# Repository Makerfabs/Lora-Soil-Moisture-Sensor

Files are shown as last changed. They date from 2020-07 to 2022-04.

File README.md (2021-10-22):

# Lora Soil Moisture Sensor

[toc]

# Makerfabs

[Makerfabs home page](https://www.makerfabs.com/)

[Makerfabs Wiki](https://makerfabs.com/wiki/index.php?title=Main_Page)

# Lora Soil Moisture Sensor

## Introduce

Product Link: [Lora_Soil_Moisture_Sensor](https://www.makerfabs.com/lora-soil-moisture-sensor.html)

Wiki Link:  [Lora_Soil_Moisture_Sensor_V3](https://www.makerfabs.com/wiki/index.php?title=Lora_Soil_Moisture_Sensor_V3)

The Lora soil moisture sensor is based on Atmel's Atmega328P, it collects local air temperature/ humidity with sensor AHT10, and detect the soil humidity with capacitor-humility measurement solution with MCU clock, and transmit the local environment data to the gateway, with Lora communication, suit for applications for smart-farm, irrigation, agriculture, etc. 

In applications, always you do not need to check the air/soil state continuously, have a test of them for few seconds after then minutes/hours sleeping is normally Ok for most projects. To save power, there the Air/ Soil measuring functional could be shut down in the working, so they can be only powered ON a short time and then a long time power off. With MCU in sleeping mode and low power consumption Lora module, this module works ok with 2 AAA battery more than one year. Besides, this sensor is coated with waterproof paint, which makes it longer working time in damp soil. 

## Feature

- Classic ATMEL AVR 8-bit Atmega328P, with Arduino Pro Mini(3.3V/8M bootloader pre-loaded) .
- Capacitor-humility measurement.
- AHT10 temperature and humidity sensor.
- Working with 2 AAA more than one years.
- 3D printed case.
- Waterproof coating.
- Unique ID, can be used directly without secondary programming.

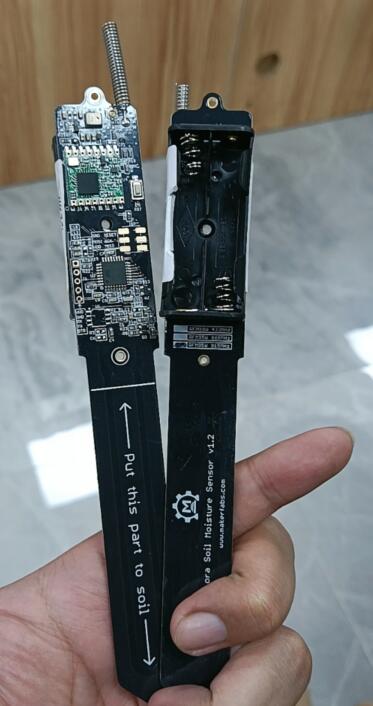
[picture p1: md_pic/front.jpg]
front


# Version
## V3 
In the latest version, the 555 chip has been removed so that the sleep current can be as low as 7.1uA. And added UID, can be used directly.

**More details, see readme. md in the [V3](https://github.com/Makerfabs/Lora-Soil-Moisture-Sensor/tree/master/V3) folder.**

## V2
Old version, containing 555 chip. A number of items are provided as references.

**More details, see readme. md in the [V2](https://github.com/Makerfabs/Lora-Soil-Moisture-Sensor/tree/master/V2) folder.**

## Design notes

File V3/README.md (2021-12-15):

# Lora Soil Moisture Sensor V3

```c++
/*
Version:		V5.0
Author:			UNKOWN
Create Date:	UNKOWN
Note:
	2021/12/15	V5.2: Fix RadioHead demo can't setModemConfig. 
	2021/11/17  V5.1: Fix code bug,example "ESP32 Receiver" pin define wrong.
	2021/10/22	V5.0: Modify the document structure. 
	2021/9/26	V4.0: The new hardware removed the 555 chip, updated the BOM, and significantly improved battery life.
	2021/8/24	V3.1: Now can read ADC value without 555.
	2021/7/22	V3.0: Now support Lorawan to TTN.
	2020/10/26	v2.2: Add a power-save verson.Using watch dog and sleep mode.
	2020/8/24	v2.1: Add pcb file.
    2020/7/24	v2.0: Rebuid readme,add pic. By Vincent
*/
```

[toc]

# Makerfabs

[Makerfabs home page](https://www.makerfabs.com/)

[Makerfabs Wiki](https://makerfabs.com/wiki/index.php?title=Main_Page)

# Lora Soil Moisture Sensor V3

## Introduce

Product Link: [Lora_Soil_Moisture_Sensor](https://www.makerfabs.com/lora-soil-moisture-sensor.html)

Wiki Link:  [Lora_Soil_Moisture_Sensor_V3](https://www.makerfabs.com/wiki/index.php?title=Lora_Soil_Moisture_Sensor_V3)

The Lora soil moisture sensor is based on Atmel's Atmega328P, it collects local air temperature/ humidity with sensor AHT10, and detect the soil humidity with capacitor-humility measurement solution with MCU clock, and transmit the local environment data to the gateway, with Lora communication, suit for applications for smart-farm, irrigation, agriculture, etc. 

In applications, always you do not need to check the air/soil state continuously, have a test of them for few seconds after then minutes/hours sleeping is normally Ok for most projects. To save power, there the Air/ Soil measuring functional could be shut down in the working, so they can be only powered ON a short time and then a long time power off. With MCU in sleeping mode and low power consumption Lora module, this module works ok with 2 AAA battery more than one year. Besides, this sensor is coated with waterproof paint, which makes it longer working time in damp soil. 

## Feature

- Classic ATMEL AVR 8-bit Atmega328P, with Arduino Pro Mini(3.3V/8M bootloader pre-loaded) .
- Capacitor-humility measurement.
- AHT10 temperature and humidity sensor.
- Working with 2 AAA more than one years.
- 3D printed case.
- Waterproof coating.
- Unique ID, can be used directly without secondary programming.

front

## Hardware Update

We removed the 555 chip and made a lot of changes to the code. The current soil moisture test uses MCU clock pulses instead of those generated by the 555 chip. Sleep mode has also been optimized more.

Detailed power consumption data is being edited....

## Firmware

### Moisture_LowPower_RadioLib_v2.1.ino

The latest firmware is in:

V3\firmware\Moisture_LowPower_RadioLib_v2.1

### How to use
- The code contains a unique ID and sends Lora messages every 75 minutes in the following format:

```c++
String message = 
    "INEDX:" + (String)packetnum + " H:" + (String)humidity + 
    " T:" + (String)temperature + " ADC:" + (String)sensorValue + 
    " BAT:" + (String)batValue;

String back_str = node_id + " REPLY : SOIL " + message;

//Full message example:
//ID010123 REPLY : SOIL INEDX:0 H:48.85 T:30.50 ADC:896 BAT:1016
```

- If you want to change the time, you can change it:

```c++
//Set sleep time, when value is 1 almost sleep 20s,when value is 450, almost 1 hour.
//Each sleep cycle almost 8s.
#define SLEEP_CYCLE 1

```

- The degree of soil ADC is about 900 in air (completely dry) and 600 in water (completely wet).

## Usage

### Receiver

A simple receiver demo is provided. You can use another Lora Moisture or Maduino Lora Radio as the receiver.

Receive data through serial port display.

The receiver code is in: V3\example\Lora_Receiver_v1.0

### ESP32 Receiver

A simple receiver demo is provided. You can use a MakePython Lora as the receiver.

Receive data and display on SSD1306.

### RadioHead Demo

The default parameters of RadioLib can reach about 800m communication distance, of course can be further, but we do not have time to debug Lora parameters.

We provide an example that can reach 1.7km communication distance, which was debugged by a former colleague. It used to depend on some AVR libraries This made ESP32 unable to complier ReadHead library at the time, so we switched to RadioLib instead. But the latest version, ReadHead is available under ESP32.

Please download the latest [RadioHead](http://www.airspayce.com/mikem/arduino/RadioHead/)

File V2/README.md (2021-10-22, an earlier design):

# Lora-Soil-Moisture-Sensor V2

```c++
/*
Version:		V4.0
Author:			UNKOWN
Create Date:	UNKOWN
Note:
	2021/9/26	V4.0: The new hardware removed the 555 chip, updated the BOM, and significantly improved battery life.
	2021/8/24	V3.1: Now can read ADC value without 555.
	2021/7/22	V3.0: Now support Lorawan to TTN.
	2020/10/26	v2.2: Add a power-save verson.Using watch dog and sleep mode.
	2020/8/24	v2.1: Add pcb file.
    2020/7/24	v2.0: Rebuid readme,add pic. By Vincent
*/
```

[toc]

# *Only available before October 2021, including the 555 chip version.*

# Introduce

The Lora soil moisture sensor is based on Atmel's Atmega328P, it collect local air temperature/ humidity with sensor AHT10, and detect the soil humidity with capacitor-humility measurement solution with 555, and transmit the local environment data to the gateway, with Lora communication, suit for applications for smart-farm, irrigation, agriculture, etc.

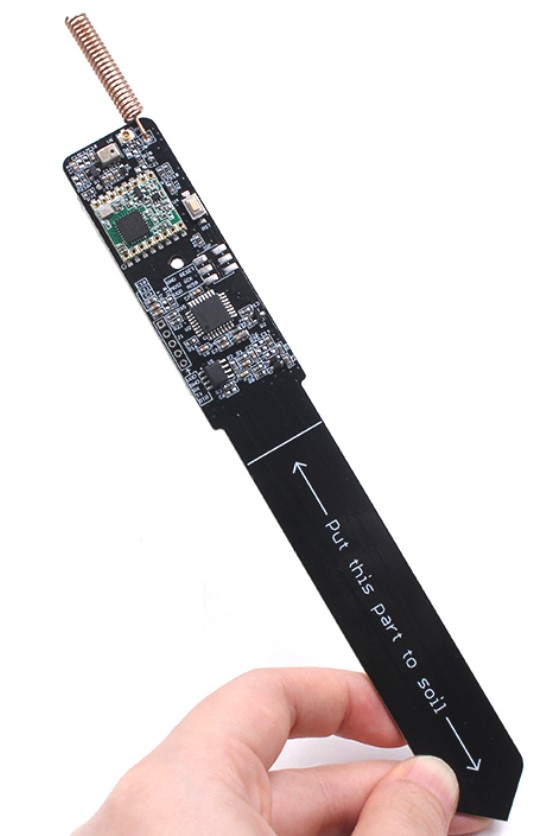
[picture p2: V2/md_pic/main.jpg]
relay


- You can get one from: [Lora_Soil_Moisture_Sensor](https://www.makerfabs.com/lora-soil-moisture-sensor.html)

- Hardware and detailed instructions please visit Wiki page:  [Lora_Soil_Moisture_Sensor Wiki](https://www.makerfabs.com/wiki/index.php?title=Lora_Soil_Moisture_Sensor)

# Related Projects

## [Project_Soil-Moisture-Sensor-Wifi](https://github.com/Makerfabs/Project_Soil-Moisture-Sensor-Wifi)

- Control relay through wifi.

- [youtube:Lora soil moisture wifi](https://youtu.be/1wYAwtzNxJU)

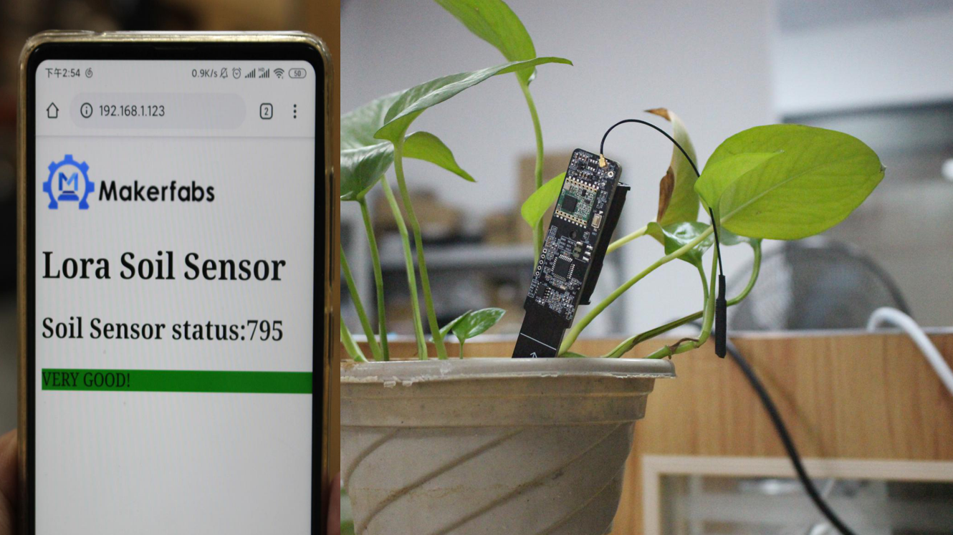
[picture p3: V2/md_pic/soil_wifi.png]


## [Lora IoT Irrigation System](https://github.com/Makerfabs/Project_IoT-Irrigation-System)

- IoT agricultural irrigation experiment based on Lora communication.
- [YOUTUBE:Lora IoT Irrigation System - Outdoor Simulation Test](https://youtu.be/0mY6Ox0YvRk)

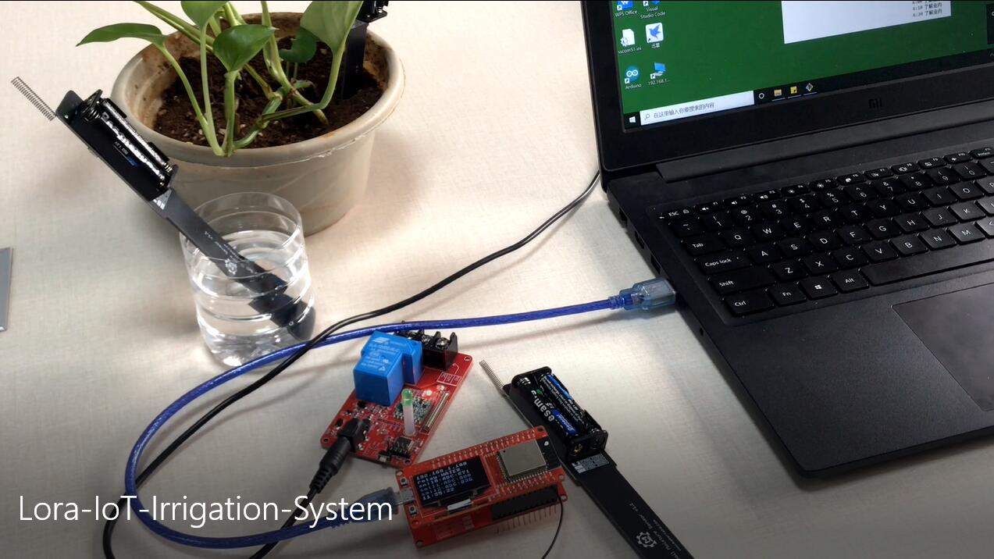
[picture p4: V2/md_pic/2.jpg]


# Example List

## LoraTransmitterADCAHT10

Default factory firmware, can measure air temperature and humidity and soil moisture, and send through Lora.

## PowerSaveMode_SoilSensor

By putting the 328p and SX1278 to sleep, you can reduce power consumption by waking them up regularly.

## lora_soil_no555

Instead of the 555 chip, we can divide the clock source by 328P.

Need to remove the R3 resistor from the PCB. And ADC results may be different from previous ones, around 910 in air and 740 in water.

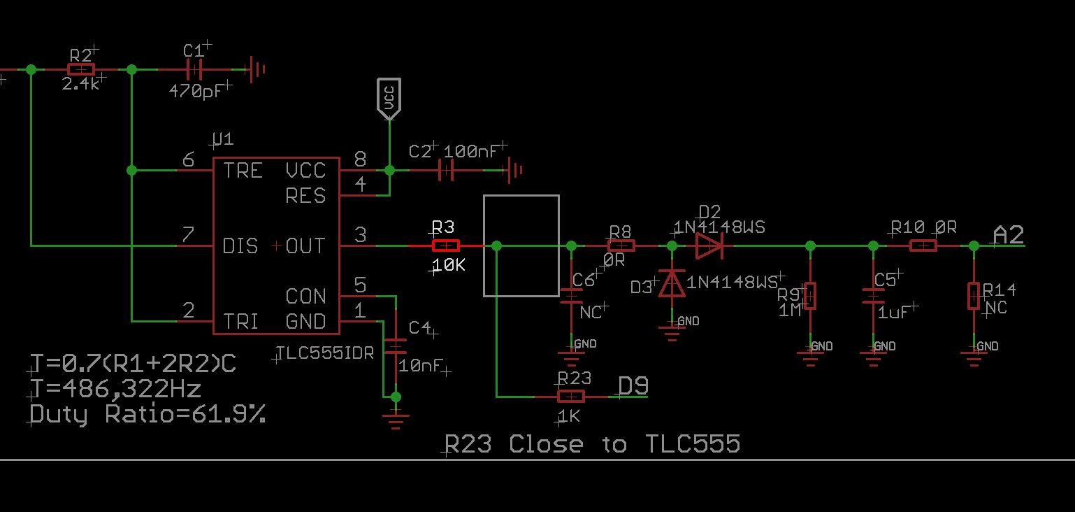
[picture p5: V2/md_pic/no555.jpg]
no555


## About Lorawan

An example of connecting to Lorawan is provided.For details on how to set TTN, see the Wiki：[Maduino_Zero_LoRaWAN_Node](https://www.makerfabs.com/wiki/index.php?title=Maduino_Zero_LoRaWAN_Node)

**Only supporting the EU-868 and US-915**

### Setup Library

Download from ：[arduino-lmic](https://github.com/matthijskooijman/arduino-lmic)

And installer .zip library

### Set EUI

To connect through OTAA, you need to replace the following code with your own DEVEUI, APPEUI, and APPKEY.

Notice that DEVEUI and APPEUI are little-endian, but APPKEY is big endian.

```c++
// This EUI must be in little-endian format, so least-significant-byte
// first. When copying an EUI from ttnctl output, this means to reverse
// the bytes. For TTN issued EUIs the last bytes should be 0xD5, 0xB3,
// 0x70.
//70B3D57ED0041DA0
//static const u1_t PROGMEM APPEUI[8]={ 0x70, 0xB3, 0xD5, 0x7E, 0xD0, 0x04, 0x1D, 0xA0 };
static const u1_t PROGMEM APPEUI[8]={ 0xA0, 0x1D, 0x04, 0xD0, 0x7E, 0xD5, 0xB3, 0x70 };
void os_getArtEui (u1_t* buf) { memcpy_P(buf, APPEUI, 8);}

// This should also be in little endian format, see above.
//D896E0FF00000888
//static const u1_t PROGMEM DEVEUI[8]={ 0xD8, 0x96, 0xE0, 0xFF, 0x00, 0x00, 0x08, 0x88 };
static const u1_t PROGMEM DEVEUI[8]={ 0x88, 0x08, 0x00, 0x00, 0xFF, 0xE0, 0x96, 0xD8 };
void os_getDevEui (u1_t* buf) { memcpy_P(buf, DEVEUI, 8);}

// This key should be in big endian format (or, since it is not really a
// number but a block of memory, endianness does not really apply). In
// practice, a key taken from ttnctl can be copied as-is.
// The key shown here is the semtech default key.
//DBA8 0380 77B1 42A7 3CFA D1EB 2F0C 8FC4
static const u1_t PROGMEM APPKEY[16] = { 0xDB, 0xA8, 0x03, 0x80, 0x77, 0xB1, 0x42, 0xA7, 0x3C, 0xFA, 0xD1, 0xEB, 0x2F, 0x0C, 0x8F, 0xC4 };
//static const u1_t PROGMEM APPKEY[16] = { 0xC4, 0x8F, 0x0C, 0x2F, 0xEB, 0xD1, 0xFA, 0x3C, 0xA7, 0x42, 0xB1, 0x77, 0x80, 0x03, 0xA8, 0xDB };
void os_getDevKey (u1_t* buf) {  memcpy_P(buf, APPKEY, 16);}
```

The code locations are /lorawan/OTAA_328p and /lorawan/OTAA_soil.

It takes a long, patient wait to connect, about 3 to 10 minutes. I don't know why.

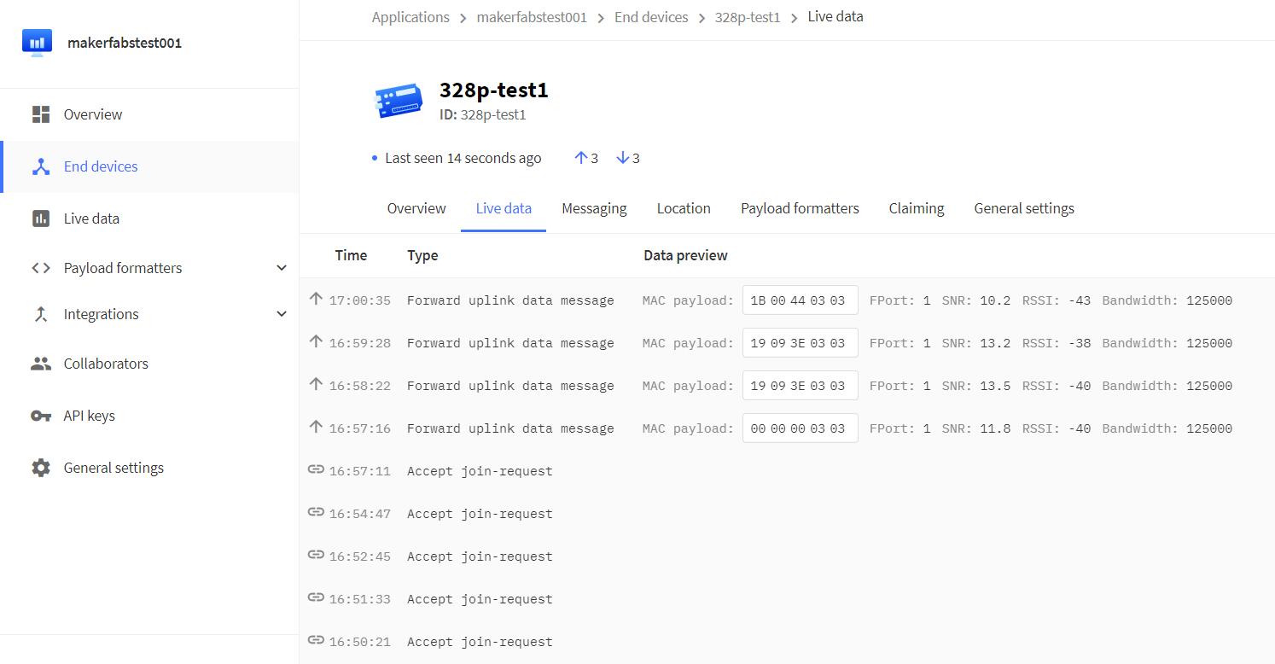
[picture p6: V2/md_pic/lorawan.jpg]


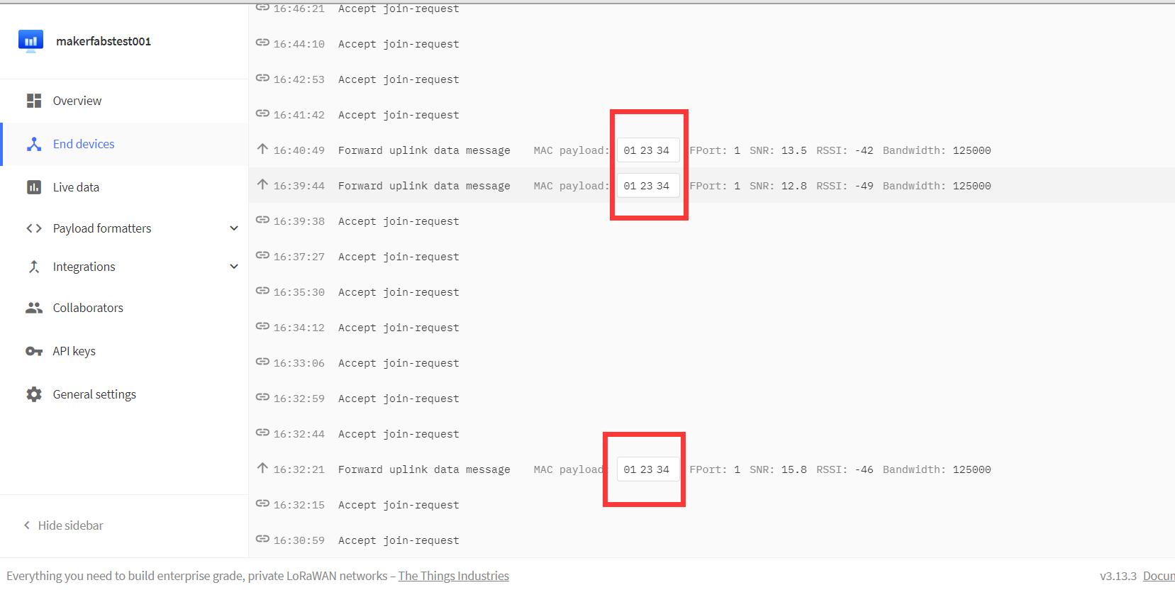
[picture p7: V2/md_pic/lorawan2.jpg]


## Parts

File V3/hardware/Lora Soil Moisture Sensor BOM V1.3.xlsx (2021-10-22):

Lora Capacitive Soil Moisture Sensor v1.3
Part | Value | Device | Package | Description | Qty
双面胶 |  |  |  |  | 1 | 双面胶将电池座黏到PCB上之后焊接
BAT1 | 2节AAA电池座，带针 |  |  |  | 1
ANT | 天线座 | ANTENNA-U-FL | 4P-U-FL |  | 1
C10,C11,C13,C14 | 10uF | C-0603 | 0603 | Ceramic Capacitors | 4
C1 | 470pF,0603 | C-0603 | 0603 |  | 1
C2,C3,C7,C8,C9,C12,C16,C18,C19 | 100nF | C-0603 | 0603 |  | 9
C4 | 10nF | C-0603 | 0603 |  | 1
C5 | 1uF | C-0603 | 0603 |  | 1
D2,D3,D4 | 1N4148WS | SOD-323 | SOD-323 |  | 3
R5,R9,R26 | 1M/1% | R-0603 | R0603 |  | 4
R27 | 470K/1% | R-0603 | R0603 |  | 1
R4,R12,R15,R22, | 10K | R-0603 | R0603 |  | 5
R13,R23 | 1K | R-0603 | R0603 |  | 2
R2 | 2.4K | R-0603 | R0603 |  | 1
R1 | 1.5k | R-0603 | R0603 |  | 1
R11,R7 | 100K/1% | R-0603 | R0603 |  | 2
R6,R8,R10,R16,R17,R18,R19,R20,R24 | 0R | R-0603 | R0603 |  | 9
U2 | ATMEGA328P | TQFP32 | TQFP32 | MICROCONTROLLER | 1
U4 | Lora模块，433M/868M/915M |  |  |  | 1 | 订单不同，模块不同，配相应频段的天线
U6 | AHT10 |  |  |  | 1
Q2 | AO3400 | SOT23 |  |  | 1
Q1 | AO3401 | SOT23 |  |  | 1
Y1 | CSTCE8M00,8MHZ,3P | SMD3213 | RESONATOR |  | 1
RST | 贴片按键，2P,6.0*3.5 |  |  |  | 1
小标签贴纸 | 背粘胶亚银标签，20mm*6mm,圆角，范围ID010000至ID019999 |  |  | 贴在PCBA上 | 1
大标签贴纸 | 背粘胶亚银标签，30mm*10mm,圆角,范围ID010000至ID019999 |  |  | 贴在外壳上 | 1
三防漆-国产J3166型号的漆 | 要求对板子进行喷三防油漆处理 |  |  | J3166型号漆
868Mhz/915MHz弹簧天线 |  |  |  |  | 1
433Mhz弹簧天线 |  |  |  |  | 1

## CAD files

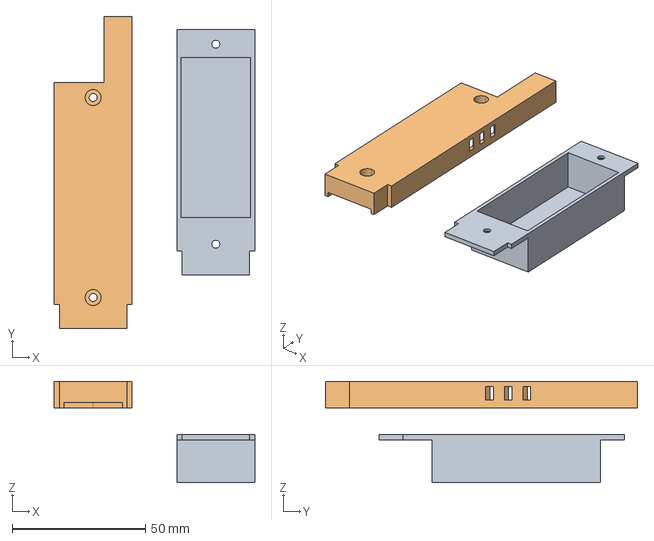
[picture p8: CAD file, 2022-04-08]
V3/hardware/lora_moisture_case.stp
75.2 x 117.0 x 38.0 mm

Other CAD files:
V3/hardware/Makerfabs Lora moisitor case v1.stl
V2/hardware/Makerfabs Lora moisitor case v1.stl

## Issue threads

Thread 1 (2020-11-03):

Connect to LoraWan / TheThingsNetwork

jdegger, 2020-11-03:
Hi,

I'm experimenting with my sensor, however it is not completely clear to me how I would proceed with connecting the sensor to LoraWan. Is this a possibility of completely out of scope of this project?

Thanks.

Makerfabs, 2020-11-04:
Hi,

I do not know if this email can find you… seems this is a github message…

The sensor is a Lora node, based on 328P and Lora module SX127x, for LoraWAN, theoretically, it is OK, that you program the 328P with firmware that supports LoraWAN, but as I know, it should be not easy.

Basically, we treat this sensor as a separate lora node, without lorawan support.

Best Regards

-----------------------------
Kevin
www.makerfabs.com

发件人: Jesse Degger [mailto:notifications@github.com]
发送时间: 2020年11月3日 18:31
收件人: Makerfabs/Lora-Soil-Moisture-Sensor
抄送: Subscribed
主题: [Makerfabs/Lora-Soil-Moisture-Sensor] Connect to LoraWan / TheThingsNetwork (#1)

Hi,

I'm experimenting with my sensor, however it is not completely clear to me how I would proceed with connecting the sensor to LoraWan. Is this a possibility of completely out of scope of this project?

Thanks.

—
You are receiving this because you are subscribed to this thread.
Reply to this email directly, view it on GitHub <https://github.com/Makerfabs/Lora-Soil-Moisture-Sensor/issues/1> , or unsubscribe <https://github.com/notifications/unsubscribe-auth/AHZNOCCRK7GTDXJO3TOU7UDSN7LU5ANCNFSM4TISCR2Q> .图像已被发件人删除。

jdegger, 2020-11-04:
Thank you Kevin, I am receiving your reply just fine.

Would makerfabs be willing to look into LoraWan support as it's a very interesting technique to add to the support list?

Makerfabs, 2020-11-04:
Er, no.. it would be difficult to support the lorawan.   Actually, if you need Lorawan, there already some IC/module that integrated the lorawan protocol

发件人: Jesse Degger [mailto:notifications@github.com]
发送时间: 2020年11月4日 15:02
收件人: Makerfabs/Lora-Soil-Moisture-Sensor
抄送: Makerfabs; Comment
主题: Re: [Makerfabs/Lora-Soil-Moisture-Sensor] Connect to LoraWan / TheThingsNetwork (#1)

Thank you Kevin, I am receiving your reply just fine.

Would makerfabs be willing to look into LoraWan support as it's a very interesting technique to add to the support list?

—
You are receiving this because you commented.
Reply to this email directly, view it on GitHub <https://github.com/Makerfabs/Lora-Soil-Moisture-Sensor/issues/1#issuecomment-721551001> , or unsubscribe <https://github.com/notifications/unsubscribe-auth/AHZNOCEJ2ZLBV2MVFRCIM6DSOD36LANCNFSM4TISCR2Q> .图像已被发件人删除。

jdegger, 2020-11-04:
> Actually, if you need Lorawan, there already some IC/module that integrated the lorawan protocol
Where can I find those? Thank you for your quick response

Makerfabs, 2020-11-04:
I believe this: CMWX1ZZABZ -078
https://www.mouser.com/ProductDetail/Murata-Electronics/CMWX1ZZABZ-078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

发件人: Jesse Degger [mailto:notifications@github.com]
发送时间: 2020年11月4日 15:26
收件人: Makerfabs/Lora-Soil-Moisture-Sensor
抄送: Makerfabs; Comment
主题: Re: [Makerfabs/Lora-Soil-Moisture-Sensor] Connect to LoraWan / TheThingsNetwork (#1)

Actually, if you need Lorawan, there already some IC/module that integrated the lorawan protocol

Where can I find those? Thank you for your quick response

—
You are receiving this because you commented.
Reply to this email directly, view it on GitHub <https://github.com/Makerfabs/Lora-Soil-Moisture-Sensor/issues/1#issuecomment-721560026> , or unsubscribe <https://github.com/notifications/unsubscribe-auth/AHZNOCA2KE6SDRJAJQBUJ3TSOD6W5ANCNFSM4TISCR2Q> .图像已被发件人删除。

jdegger, 2020-11-25:
Hi, I just wanted to let you guys know that I found out that this certainly possible. I'm on my way to make this work but I'm still having some issues. Once I have a working .ino I will share it here. I'm using https://github.com/mcci-catena/arduino-lmic to make this work.

It might be interesting for you as well to use and test this, as it might sell better with LoraWan

lzomedia, 2021-03-29:
> Hi, I just wanted to let you guys know that I found out that this certainly possible. I'm on my way to make this work but I'm still having some issues. Once I have a working .ino I will share it here. I'm using https://github.com/mcci-catena/arduino-lmic to make this work.
>
> It might be interesting for you as well to use and test this, as it might sell better with LoraWan

Interesting I'm keeping my tows in the same library I've managed to get it to

41630351: EV_TXSTART
41316692: Unknown event: 20
41316966: EV_JOIN_FAILED

mikelinton, 2021-04-16:
@jdegger I'm running into the same issue as I thought I'd be able to use these with LoRaWan/TTN. Were you ever able to get things running with TTN? Thanks in advance.

lzomedia, 2021-04-18:
So I've spent like a whole weekend trying to get it working using a library on ttn. My main problem was the fact that I don't know the pins to listen and send for the lora protocol. Indeed one to one of their thingy works . Even with the pihat again it works. I guess if they can share the schematics we can go forward and maybe could connect this to ttn. But I doubt it. More then sure the pins for in and out are being use.

lzomedia, 2021-04-18:
@mikelinton as you can see from my testing I was having issues with mapping the pins.that library will work perfectly if they can just share the pi outs . I've tried the default ones for the 128 chip and it seems they don't work.

tdvantine, 2021-12-28:
@lzomedia have you looked at the [PDF in the hardware folder](https://github.com/Makerfabs/Lora-Soil-Moisture-Sensor/blob/master/V3/hardware/Lora%20Soil%20Moisture%20Sensor%20v1.2.PDF)? It has a schematic of the circuits.
I too bought these thinking they would work with LoRaWAn, and once I them, i also realized there was no FCCID on them and to me that was a sign they would never be supported for LoRaWAN officially.

mconlow, 2022-01-29:
I also bought one of these thinking I could hook it up to LoRaWAN/TTN...

If anyone gets it working, I'd be very interested.

Has anyone found another LoRaWAN soil moisture sensor?

mconlow, 2022-01-31:
Another path might be to forego the LoraWAN and just try to use this thing P2P over LoRa which would work in my use-case.

I have the "bonnet" for the Raspberry Pi https://www.adafruit.com/product/4074
and separately I have a LoRaWAN gateway https://www.adafruit.com/product/4284

Any suggestions from anyone on a python library I could use that would work on either of these devices that could pick up the packet from this moisture sensor?

Thanks in advance

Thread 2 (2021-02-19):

Outdoor version

chamroeunbm, 2021-02-19:
Lora is for long distance communication which is more about farm rather than greenhouse so i think you better make outdoor version. For greenhouse, normal RF433 or Esp8266 is enough .

littlejogi, 2022-02-11:
An outdoor case would be great. I thought about using heat shrink tubes

i4things, 2022-02-15:
+1 for outdoor case - especially one that can withstand pouring rain a floods

garudaonekh, 2022-02-16:
> An outdoor case would be great. I thought about using heat shrink tubes

I think it is better to use PVC tube

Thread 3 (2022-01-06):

Watchdog wake up directly

littlejogi, 2022-01-06:
I have a problem with the deep sleep watch dog of the v2.1. SLEEP_CYCLE is set to 105 (~15 Minutes). For some days it works perfect. But since last night it doesnt sleep anymore and send every 5-7 seconds.
A reset brings no improvment.

littlejogi, 2022-01-06:
Here is my "working" code (TTN and private Chirpstack):
```
/* Version sends to Chirpstack; TTN also works
    based on https://github.com/Makerfabs/Lora-Soil-Moisture-Sensor/blob/master/

  Chirpstack Decoder:
  function Decode(fPort, bytes){

  var data = {
      battery:((bytes[0]) + (bytes[1]/100)),
      temperature:((bytes[2]) + (bytes[3]/100)),
      humidity:((bytes[4]) + (bytes[5]/100)),
      moisture:((bytes[6])+ (bytes[7]<<8)),
  };
  return data;
  }

*/

#include <lmic.h>
#include <hal/hal.h>
#include "I2C_AHT10.h"

#include <avr/wdt.h>
#include <avr/sleep.h>

#define M_MOSI 11
#define M_MISO 12
#define M_SCLK 13
#define M_CS 10
#define M_DIO0 2
#define M_DIO1 6
#define M_DIO2 7
#define M_DIO5 8
#define M_RST 9

#define DEBUG_OUT_ENABLE 0
//Set sleep time, when value is 1 almost sleep 20s,when value is 450, almost 1 hour.
#define SLEEP_CYCLE 104 // 8 ca. 64 Sek., 104 ca. 15 Min.

#define SENSOR_POWER_PIN 5

int ADC_O_1;           // ADC Output First 8 bits
int ADC_O_2;           // ADC Output Next 2 bits

AHT10 humiditySensor;

int sensorPin = A2;  // select the input pin for the potentiometer
int sensorValue = 0; // variable to store the value coming from the sensor
int sensorPowerCtrlPin = 5;
int PWM_OUT_PIN = 9;

int16_t packetnum = 0;   // packet counter, we increment per xmission
float temperature = 0.0; //
float humidity = 0.0;
int batValue = 0;    // the voltage of battery
int count = 0;

#define LMIC_DEBUG_LEVEL 2

static const PROGMEM u1_t NWKSKEY[16] = { /* tbd */};
static const u1_t PROGMEM APPSKEY[16] = { /* tbd */ };
static const u4_t DEVADDR = /* tbd */;

// These callbacks are only used in over-the-air activation, so they are
// left empty here (we cannot leave them out completely unless
// DISABLE_JOIN is set in config.h, otherwise the linker will complain).
void os_getArtEui (u1_t* buf) { }
void os_getDevEui (u1_t* buf) { }
void os_getDevKey (u1_t* buf) { }

static uint8_t mydata[] = {0xFF, 0x00, 0x00, 0x00, 0x00, 0x00, 0x00, 0x00, 0x00};

static osjob_t sendjob;

// Pin mapping
const lmic_pinmap lmic_pins = {
  .nss = M_CS,
  .rxtx = LMIC_UNUSED_PIN,
  .rst = M_RST,
  .dio = {M_DIO0, M_DIO1, M_DIO2},
};

void do_send(osjob_t *j)
{
  // Check if there is not a current TX/RX job running
  if (LMIC.opmode & OP_TXRXPEND)
  {
    Serial.println(F("OP_TXRXPEND, not sending"));
  }
  else
  {
    // Prepare upstream data transmission at the next possible time.
    LMIC_setTxData2(1, mydata, sizeof(mydata) - 1, 0);
#if DEBUG_OUT_ENABLE
    Serial.print(F("Packet queued"));
    Serial.print(": (0) " + String(mydata[0]));
    Serial.print(", (1) " + String(mydata[1]));
    Serial.print(", (2) " + String(mydata[2]));
    Serial.print(", (3) " + String(mydata[3]));
    Serial.print(", (4) " + String(mydata[4]));
    Serial.print(", (5) " + String(mydata[5]));
    Serial.print(", (6) " + String(mydata[6]));
    Serial.println(", (7) " + String(mydata[7]));
#endif
  }
}

void readSensor()
{
  sensorPowerOn();
  digitalWrite(SENSOR_POWER_PIN, HIGH); // Sensor/RF95 power on
  delay(100);
  digitalWrite(SENSOR_POWER_PIN, HIGH); // Sensor/RF95 power on

  pinMode(PWM_OUT_PIN, OUTPUT);    //digitalWrite(PWM_OUT_PIN, LOW);
  TCCR1A = bit(COM1A0);            // toggle OC1A on Compare Match
  TCCR1B = bit(WGM12) | bit(CS10); // CTC, scale to clock
  OCR1A = 1;                       // compare A register value (5000 * clock speed / 1024).When OCR1A == 1, PWM is 2MHz

  //ADC2  AVCC as reference voltage
  ADMUX = _BV(REFS0) | _BV(MUX1);

  ADCSRA = _BV(ADEN) | _BV(ADPS1) | _BV(ADPS0);
  delay(50);
  for (int i = 0; i < 3; i++)
  {
    //start ADC conversion
    ADCSRA |= (1 << ADSC);

    delay(10);

    if ((ADCSRA & 0x40) == 0)
    {
      ADC_O_1 = ADCL;
      ADC_O_2 = ADCH;

      sensorValue = (ADC_O_2 << 8) + ADC_O_1;
      ADCSRA |= 0x40;
#if DEBUG_OUT_ENABLE
      Serial.print("ADC:");
      Serial.println(sensorValue);
#endif
      AHT_init();
    }
    ADCSRA |= (1 << ADIF); //reset as required
    delay(50);
  }

#if DEBUG_OUT_ENABLE
  Serial.print(F("Moisture ADC : "));
  Serial.println(sensorValue);
#endif

  delay(200);

  // Read battery value
  int ADC_O_1;           // ADC Output First 8 bits
  int ADC_O_2;           // ADC Output Next 2 bits
  //ADC3  internal 1.1V as ADC reference voltage
  ADMUX = _BV(REFS1) | _BV(REFS0) | _BV(MUX1) | _BV(MUX0);

  delay(50);
  for (int i = 0; i < 3; i++)
  {
    //start ADC conversion
    ADCSRA |= (1 << ADSC);
    delay(10);
    if ((ADCSRA & 0x40) == 0)
    {
      ADC_O_1 = ADCL;
      ADC_O_2 = ADCH;
      batValue = (ADC_O_2 << 8) + ADC_O_1;
      ADCSRA |= 0x40;
      float bat = (float)batValue * 3.3;
      bat = bat / 1024.0;
    }
    ADCSRA |= (1 << ADIF); //reset as required
    delay(50);
  }
  float bat = (float)batValue * 3.3;
  bat = bat / 1024.0;
#if DEBUG_OUT_ENABLE
  Serial.print("BAT: ");
  Serial.print(bat);
  Serial.println("V");

  // Read temperature and humidity
  Serial.println("Humidity-Sensor available? " + String(humiditySensor.available() == true));
#endif
  //  if (humiditySensor.available() == true)
  {
    //Get the new temperature and humidity value
    temperature = humiditySensor.getTemperature();
    humidity = humiditySensor.getHumidity();
#if DEBUG_OUT_ENABLE
    //Print the results
    Serial.print("Temperature: ");
    Serial.print(temperature, 2);
    Serial.println(" C\t");
    Serial.print("Humidity: ");
    Serial.print(humidity, 2);
    Serial.println("% RH");
#endif
  }
  // Check if any reads failed and exit early (to try again).
  if (isnan(humidity) || isnan(temperature))
  {
    Serial.println(F("Failed to read from AHT sensor!"));
    //return;
  }

  delay(100);
  sensorPowerOff();

  // calcuate values and prepare lora data
  int bat1 = int(bat);
  float bat2 = (bat - bat1) * 100;

  int temp1 = int(temperature);
  float temp2 = (temperature - temp1) * 100;

  int hum1 = int(humidity);
  float hum2 = (humidity - hum1) * 100;

  mydata[0] = uint8_t(bat1);
  mydata[1] = uint8_t((int)bat2);
  mydata[2] = uint8_t(temp1);
  mydata[3] = uint8_t((int)temp2);
  mydata[4] = uint8_t(hum1);
  mydata[5] = uint8_t((int)hum2);
  mydata[6] = uint8_t(sensorValue );
  mydata[7] = uint8_t((sensorValue & 0xff00) >> 8);
}

void sensorPowerOn(void)
{
  digitalWrite(sensorPowerCtrlPin, HIGH); //Sensor power on
}

void sensorPowerOff(void)
{
  digitalWrite(sensorPowerCtrlPin, LOW); //Sensor power off
}

ISR(WDT_vect)
{
#if DEBUG_OUT_ENABLE
  Serial.print("[Watch dog]");
  Serial.println(count);
#endif
  delay(100);
  count++;
  //wdt_reset();
  wdt_disable(); // disable watchdog
}

//Set low power mode and into sleep
void low_power_set()
{
  all_pins_low();
  delay(10);
  // disable ADC
  ADCSRA = 0;

  sleep_enable();
  watchdog_init();
  set_sleep_mode(SLEEP_MODE_PWR_DOWN);
  delay(10);
  noInterrupts();
  sleep_enable();

  // turn off brown-out enable in software
  MCUCR = bit(BODS) | bit(BODSE);
  MCUCR = bit(BODS);
  interrupts();

  sleep_cpu();
  sleep_disable();
}

//Enable watch dog
void watchdog_init()
{
  // clear various "reset" flags
  MCUSR = 0;
  // allow changes, disable reset
  WDTCSR = bit(WDCE) | bit(WDE);
  WDTCSR = bit(WDIE) | bit(WDP3) | bit(WDP0); // set WDIE, and 8 seconds delay
  wdt_reset();                                // pat the dog
}

void all_pins_low()
{
  pinMode(PWM_OUT_PIN, INPUT);
  pinMode(A4, INPUT_PULLUP);
  pinMode(A5, INPUT_PULLUP);
  delay(50);
}

bool AHT_init()
{
  bool ret = false;
  Wire.begin();
  if (humiditySensor.begin() == false)
  {
#if DEBUG_OUT_ENABLE
    Serial.println("AHT10 not detected. Please check wiring. Freezing.");
#endif
  }

  if (humiditySensor.available() == true)
  {
    temperature = humiditySensor.getTemperature();
    humidity = humiditySensor.getHumidity();
    ret = true;
  }
  if (isnan(humidity) || isnan(temperature))
  {
#if DEBUG_OUT_ENABLE
    Serial.println(F("Failed to read from AHT sensor!"));
#endif
  }
  return ret;
}

void setup() {
  pinMode(sensorPowerCtrlPin, OUTPUT);
  // set up Timer 1
  pinMode(PWM_OUT_PIN, OUTPUT);

  TCCR1A = bit(COM1A0);            // toggle OC1A on Compare Match
  TCCR1B = bit(WGM12) | bit(CS10); // CTC, scale to clock
  OCR1A = 1;

  Serial.begin(115200);
#if DEBUG_OUT_ENABLE
  Serial.println(F("Starting"));
#endif

  do_job();
  low_power_set();
}

void initalize() {
  // initialize every sending loop (lora)
  sensorPowerOn();

  Wire.begin(); //Join I2C bus
  //Check if the AHT10 will acknowledge
  if (humiditySensor.begin() == false)
  {
    Serial.println("AHT10 not detected. Please check wiring. Freezing.");
    //while (1);
  }
  else
  {
#if DEBUG_OUT_ENABLE
    Serial.println("AHT10 acknowledged.");
#endif
  }

  readSensor();
  // LMIC init
  os_init();
  // Reset the MAC state. Session and pending data transfers will be discarded.
  LMIC_reset();

  // Set static session parameters. Instead of dynamically establishing a session
  // by joining the network, precomputed session parameters are be provided.
  uint8_t appskey[sizeof(APPSKEY)];
  uint8_t nwkskey[sizeof(NWKSKEY)];
  memcpy_P(appskey, APPSKEY, sizeof(APPSKEY));
  memcpy_P(nwkskey, NWKSKEY, sizeof(NWKSKEY));
  LMIC_setSession (0x1, DEVADDR, nwkskey, appskey);

  LMIC_setupChannel(0, 868100000, DR_RANGE_MAP(DR_SF12, DR_SF7),  BAND_CENTI);      // g-band
  LMIC_setupChannel(1, 868300000, DR_RANGE_MAP(DR_SF12, DR_SF7B), BAND_CENTI);      // g-band
  LMIC_setupChannel(2, 868500000, DR_RANGE_MAP(DR_SF12, DR_SF7),  BAND_CENTI);      // g-band
  LMIC_setupChannel(3, 867100000, DR_RANGE_MAP(DR_SF12, DR_SF7),  BAND_CENTI);      // g-band
  LMIC_setupChannel(4, 867300000, DR_RANGE_MAP(DR_SF12, DR_SF7),  BAND_CENTI);      // g-band
  LMIC_setupChannel(5, 867500000, DR_RANGE_MAP(DR_SF12, DR_SF7),  BAND_CENTI);      // g-band
  LMIC_setupChannel(6, 867700000, DR_RANGE_MAP(DR_SF12, DR_SF7),  BAND_CENTI);      // g-band
  LMIC_setupChannel(7, 867900000, DR_RANGE_MAP(DR_SF12, DR_SF7),  BAND_CENTI);      // g-band
  LMIC_setupChannel(8, 868800000, DR_RANGE_MAP(DR_FSK,  DR_FSK),  BAND_MILLI);      // g2-band

  //LMIC_disableChannel(0); //Send only at channel 0
  LMIC_disableChannel(1);
  LMIC_disableChannel(2);
  LMIC_disableChannel(3);
  LMIC_disableChannel(4);
  LMIC_disableChannel(5);
  LMIC_disableChannel(6);
  LMIC_disableChannel(7);
  LMIC_disableChannel(8);

  // Disable link check validation
  LMIC_setLinkCheckMode(0);

  // TTN uses SF9 for its RX2 window.
  LMIC.dn2Dr = DR_SF9;

  // Set data rate and transmit power for uplink (note: txpow seems to be ignored by the library)
  LMIC_setDrTxpow(DR_SF7, 14);

}

void do_job() {
  initalize();
  do_send(&sendjob);
}

void loop() {

  wdt_disable();
  if (count > SLEEP_CYCLE) //(7+1) x 8S  450
  {
#if DEBUG_OUT_ENABLE
    //code start
    Serial.println("Code start>>");
#endif

    do_job();
    //        all_pins_low();

#if DEBUG_OUT_ENABLE
    //code end
    Serial.println("Code end<<");
#endif
    //count init
    count = 0;
  }

  low_power_set();
}
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

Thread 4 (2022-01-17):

the unit will not program

seamaster101, 2022-01-17:
I can compile your sample, but when i try to upload the upload fails.
I'm using this programmer: [https://www.amazon.ca/DSD-TECH-Adapter-FT232RL-Compatible/dp/B07BBPX8B8](url)
the programmer is set to 3.3V
I tried connecting the DTR to the reset line on the programmer and to the DTR line on the programmer (it has pad an the board that I pulled out for that)
in both cases the programming fails, but when the unit is powered I can see communication on the serial port:
*********************
Soil start.
success!
AHT10 acknowledged.
success!
ADC:888
ADC:894
ADC:894
BAT:1006
3.24VBAT:1006
3.24VBAT:1006
3.24VID010209 REPLY : SOIL INEDX:0 H:39.58 T:25.84 ADC:894 BAT:1006
[Set]Sleep Mode Set
[Watch dog]0
***********************
etc. etc.....
I have the board setup as Arduino UNO with processor ATmega328P
here is the error message when i try to upload code:
***************************************************************************************************
Arduino: 1.8.19 (Windows Store 1.8.57.0) (Windows 10), Board: "Arduino Nano, ATmega328P"

Sketch uses 23508 bytes (76%) of program storage space. Maximum is 30720 bytes.

Global variables use 1028 bytes (50%) of dynamic memory, leaving 1020 bytes for local variables. Maximum is 2048 bytes.

avrdude: stk500_getsync() attempt 1 of 10: not in sync: resp=0x53

avrdude: stk500_getsync() attempt 2 of 10: not in sync: resp=0x6f

avrdude: stk500_getsync() attempt 3 of 10: not in sync: resp=0x69

avrdude: stk500_getsync() attempt 4 of 10: not in sync: resp=0x6c

avrdude: stk500_getsync() attempt 5 of 10: not in sync: resp=0x20

avrdude: stk500_getsync() attempt 6 of 10: not in sync: resp=0x73

avrdude: stk500_getsync() attempt 7 of 10: not in sync: resp=0x74

avrdude: stk500_getsync() attempt 8 of 10: not in sync: resp=0x61

avrdude: stk500_getsync() attempt 9 of 10: not in sync: resp=0x72

avrdude: stk500_getsync() attempt 10 of 10: not in sync: resp=0x74

An error occurred while uploading the sketch
**********************************************************************

please tell me what i'm doing wrong?

littlejogi, 2022-01-19:
I select "Arduino Pro or Pro Mini" and ATMega328P (3,3V 8MHZ) and use https://www.amazon.de/gp/product/B01C2P9GD2/ref=ppx_yo_dt_b_asin_title_o03_s01?ie=UTF8&psc=1
Everything works fine. Sometimes i have some problems with the contact of the pin

roopesh, 2023-06-03:
How did you compile this?  I set the board settings (thank you!  They shouldn't make it so hard to figure out) but I still get
````
/Users/*****/Documents/Arduino/Lora-Soil-Moisture-Sensor-V3/Lora-Soil-Moisture-Sensor-V3.ino: In function 'void Lora_init()':
Lora-Soil-Moisture-Sensor-V3:86:82: error: 'SX127X_SYNC_WORD' was not declared in this scope
     int state = radio.begin(FREQUENCY, BANDWIDTH, SPREADING_FACTOR, CODING_RATE, SX127X_SYNC_WORD, OUTPUT_POWER, PREAMBLE_LEN, GAIN);
                                                                                  ^~~~~~~~~~~~~~~~
/Users/*****/Documents/Arduino/Lora-Soil-Moisture-Sensor-V3/Lora-Soil-Moisture-Sensor-V3.ino:86:82: note: suggested alternative: 'RADIOLIB_SX127X_SYNC_WORD'
     int state = radio.begin(FREQUENCY, BANDWIDTH, SPREADING_FACTOR, CODING_RATE, SX127X_SYNC_WORD, OUTPUT_POWER, PREAMBLE_LEN, GAIN);
                                                                                  ^~~~~~~~~~~~~~~~
                                                                                  RADIOLIB_SX127X_SYNC_WORD
Lora-Soil-Moisture-Sensor-V3:87:18: error: 'ERR_NONE' was not declared in this scope
     if (state == ERR_NONE)
                  ^~~~~~~~
/Users/*****/Documents/Arduino/Lora-Soil-Moisture-Sensor-V3/Lora-Soil-Moisture-Sensor-V3.ino:87:18: note: suggested alternative: 'SKIP_NONE'
     if (state == ERR_NONE)
                  ^~~~~~~~
                  SKIP_NONE
exit status 1
'SX127X_SYNC_WORD' was not declared in this scope
````

roopesh, 2023-06-06:
For anyone looking for a solution, I was able to fix it with:
````#include <SPI.h>
#include <Wire.h>
#include <RadioLib.h>
#include <avr/wdt.h>
#include <avr/sleep.h>
#include "I2C_AHT10.h"

#define ERR_NONE 0

//#define NODENAME "LORA_POWER_1"

//IMPORTANT Uncomment out this line with the right ID on the case or on the side of the sensor
//String node_id = String("ID") + "010933";

//Set sleep time, when value is 1 almost sleep 20s,when value is 450, almost 1 hour.
#define SLEEP_CYCLE 450

//Lora set
//Set Lora frequency
//Commented out any frequency in this example to make you choose the relevant one for your sensor.
//IMPORTANT Uncomment out this line with the right Frequency.
//As an aside, I was able to get all of the sensor to broadcast at 915MHz (even the ones marked 434 and 868).
//#define FREQUENCY 434.0
//#define FREQUENCY 868.0
//#define FREQUENCY 915.0

//Nothing below this line should need to be touched.
#define BANDWIDTH 125.0
#define SPREADING_FACTOR 9
#define CODING_RATE 7
#define OUTPUT_POWER 10
#define PREAMBLE_LEN 8
#define GAIN 0

//328p
#define DIO0 2
#define DIO1 6

#define LORA_RST 4
#define LORA_CS 10

#define SPI_MOSI 11
#define SPI_MISO 12
#define SPI_SCK 13

//pin set
#define VOLTAGE_PIN A3
#define PWM_OUT_PIN 9
#define SENSOR_POWER_PIN 5
#define ADC_PIN A2

#define DEBUG_OUT_ENABLE 1

SX1276 radio = new Module(LORA_CS, DIO0, LORA_RST, DIO1);
AHT10 humiditySensor;

bool readSensorStatus = false;
int sensorValue = 0; // variable to store the value coming from the sensor
int batValue = 0;    // the voltage of battery
int count = 0;
int ADC_O_1;           // ADC Output First 8 bits
int ADC_O_2;           // ADC Output Next 2 bits
int16_t packetnum = 0; // packet counter, we increment per xmission
float temperature = 0.0;
float humidity = 0.0;

bool AHT_init()
{
    bool ret = false;
    Wire.begin();
    if (humiditySensor.begin() == false)
    {
#if DEBUG_OUT_ENABLE
        Serial.println("AHT10 not detected. Please check wiring. Freezing.");
#endif
    }

    if (humiditySensor.available() == true)
    {
        temperature = humiditySensor.getTemperature();
        humidity = humiditySensor.getHumidity();
        ret = true;
    }
    if (isnan(humidity) || isnan(temperature))
    {
#if DEBUG_OUT_ENABLE
        Serial.println(F("Failed to read from AHT sensor!"));
#endif
    }
    return ret;
}
void Lora_init()
{
    int state = radio.begin(FREQUENCY, BANDWIDTH, SPREADING_FACTOR, CODING_RATE, RADIOLIB_SX127X_SYNC_WORD, OUTPUT_POWER, PREAMBLE_LEN, GAIN);
    if (state == ERR_NONE)
    {
#if DEBUG_OUT_ENABLE
        Serial.println(F("success!"));
#endif
    }
    else
    {
#if DEBUG_OUT_ENABLE
        Serial.print(F("failed, code "));
        Serial.println(state);
#endif
        // while (true)
        //     ;
    }
}
void setup()
{
#if DEBUG_OUT_ENABLE
    Serial.begin(115200);
    Serial.println("Soil start.");
#endif
    delay(100);

    // set up Timer 1
    pinMode(PWM_OUT_PIN, OUTPUT);

    TCCR1A = bit(COM1A0);            // toggle OC1A on Compare Match
    TCCR1B = bit(WGM12) | bit(CS10); // CTC, scale to clock
    OCR1A = 1;

    pinMode(LORA_RST, OUTPUT);
    digitalWrite(LORA_RST, HIGH);
    delay(100);

    pinMode(SENSOR_POWER_PIN, OUTPUT);
    digitalWrite(SENSOR_POWER_PIN, HIGH); //Sensor power on
    delay(100);

    Lora_init();

    Wire.begin();
    if (humiditySensor.begin() == false)
    {

#if DEBUG_OUT_ENABLE
        Serial.println("AHT10 not detected. Please check wiring. Freezing.");
#endif
    }
#if DEBUG_OUT_ENABLE
    else
        Serial.println("AHT10 acknowledged.");
#endif

    do_some_work();
//setup over
#if DEBUG_OUT_ENABLE
    Serial.println("[Set]Sleep Mode Set");
#endif
    low_power_set();
}

void loop()
{
    wdt_disable();

    if (count > SLEEP_CYCLE) //(7+1) x 8S  450
    {
#if DEBUG_OUT_ENABLE
        //code start
        Serial.println("Code start>>");
#endif

        do_some_work();
        all_pins_low();

#if DEBUG_OUT_ENABLE
        //code end
        Serial.println("Code end<<");
#endif
        //count init
        count = 0;
    }

    low_power_set();
}

ISR(WDT_vect)
{
#if DEBUG_OUT_ENABLE
    Serial.print("[Watch dog]");
    Serial.println(count);
#endif
    delay(100);
    count++;
    //wdt_reset();
    wdt_disable(); // disable watchdog
}

//Set low power mode and into sleep
void low_power_set()
{
    all_pins_low();
    delay(10);
    // disable ADC
    ADCSRA = 0;

    sleep_enable();
    watchdog_init();
    set_sleep_mode(SLEEP_MODE_PWR_DOWN);
    delay(10);
    noInterrupts();
    sleep_enable();

    // turn off brown-out enable in software
    MCUCR = bit(BODS) | bit(BODSE);
    MCUCR = bit(BODS);
    interrupts();

    sleep_cpu();
    sleep_disable();
}

//Enable watch dog
void watchdog_init()
{
    // clear various "reset" flags
    MCUSR = 0;
    // allow changes, disable reset
    WDTCSR = bit(WDCE) | bit(WDE);
    WDTCSR = bit(WDIE) | bit(WDP3) | bit(WDP0); // set WDIE, and 8 seconds delay
    wdt_reset();                                // pat the dog
}

void do_some_work()
{

    digitalWrite(SENSOR_POWER_PIN, HIGH); // Sensor/RF95 power on
    digitalWrite(LORA_RST, HIGH);
    delay(5);
    pinMode(PWM_OUT_PIN, OUTPUT);    //digitalWrite(PWM_OUT_PIN, LOW);
    TCCR1A = bit(COM1A0);            // toggle OC1A on Compare Match
    TCCR1B = bit(WGM12) | bit(CS10); // CTC, scale to clock
    OCR1A = 1;                       // compare A register value (5000 * clock speed / 1024).When OCR1A == 1, PWM is 2MHz

    Lora_init();
    delay(50);

    //ADC2  AVCC as reference voltage
    ADMUX = _BV(REFS0) | _BV(MUX1);

    //ADC2  internal 1.1V as ADC reference voltage
    //ADMUX = _BV(REFS1) |_BV(REFS0) | _BV(MUX1);

    // 8  分频
    ADCSRA = _BV(ADEN) | _BV(ADPS1) | _BV(ADPS0);
    delay(50);
    for (int i = 0; i < 3; i++)
    {
        //start ADC conversion
        ADCSRA |= (1 << ADSC);

        delay(10);

        if ((ADCSRA & 0x40) == 0)
        {
            ADC_O_1 = ADCL;
            ADC_O_2 = ADCH;

            sensorValue = (ADC_O_2 << 8) + ADC_O_1;
            ADCSRA |= 0x40;
#if DEBUG_OUT_ENABLE
            Serial.print("ADC:");
            Serial.println(sensorValue);
#endif

            if (readSensorStatus == false)
                readSensorStatus = AHT_init();
        }
        ADCSRA |= (1 << ADIF); //reset as required
        delay(50);
    }

    //ADC3  internal 1.1V as ADC reference voltage
    ADMUX = _BV(REFS1) | _BV(REFS0) | _BV(MUX1) | _BV(MUX0);

    delay(50);
    for (int i = 0; i < 3; i++)
    {
        //start ADC conversion
        ADCSRA |= (1 << ADSC);

        delay(10);

        if ((ADCSRA & 0x40) == 0)
        {
            ADC_O_1 = ADCL;
            ADC_O_2 = ADCH;
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
fredmccr, 2024-01-23:
Thank you roopesh for your code.
Unfortunately, I get the following error message while trying to compile it:

"text section exceeds available space in board
Sketch uses 31062 bytes (101%) of program storage space. Maximum is 30720 bytes"

I first tried to remove all the comments lines, hoping it will lighten the weight of the code .. without success.
I finally managed to get rid of this by commenting a few "serial.println..." lines that are relevant for debugging purposes only.
I hope this could help those with the same issue.

roopesh, 2024-01-23:
> I first tried to remove all the comments lines, hoping it will lighten the weight of the code .. without success. I finally managed to get rid of this by commenting a few "serial.println..." lines that are relevant for debugging purposes only. Compilation and programming are ok now. I hope this could help those with the same issue.

hahaha I didn't have that problem, but yeah remove all my extra dumb logging.  I am an Arduino newbie so I needed lots of extra help.

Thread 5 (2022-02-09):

ADC: sensorValue

i4things, 2022-02-09:
Any table that based on the sensor value to get the soil moisture in % ?

littlejogi, 2022-02-11:
i use
mprocent =(1-((moisture-560) / 324 ))*100;

I don't know how accurate this value is. For me it looks ok

i4things, 2022-02-11:
I use : mpercent = 100 - ((moisture - 500) / 4)
e.g.  500 = 100% i - 900 = 0%

but after some experiments - it looks like a better calculation should use the battery voltage also - as the battery voltage is used as a reference voltage and when the battery goes down the min/max values are changing

e.g.  battery ADC result with moisture ADC result

bat - 1023 -> moist ( 527(in water -100%) - 894 (in air - 0%) )
bat -  920  -> moist ( 508 - 880 )

e.g. I was hoping someone before me t have done some more detailed experiments :)

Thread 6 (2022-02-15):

Boot Loader  update

i4things, 2022-02-15:
I managed to damage the boot loader of my "Lora Temperature/ Humidity/ Soil Moisture Sensor V3" . Is there any standard programmer and/or adapter that I can use to upload/refresh the boot loader ?

Any suggestion will be well appreciated.

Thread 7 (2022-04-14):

Connection Issue to Receiver

MuenzPatrick, 2022-04-14:
I've got the SX1262 868M LoRa HAT for receiving lora packages.
It seems that i cant receive packages from the V3 Sensor with this device?

Do you think i can configure something to make it work?

Thanks!

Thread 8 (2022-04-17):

ESP32 [SX1278] Initializing ... failed, code -2

mconlow, 2022-04-17:
Hi,

I'm trying to get the ESP32 receiver to work with the Lora Soil Moisture Sensor.  I have RadioLib 4.6.0, though it doesn't specify anywhere exactly what version I should use. I'm in the U.S.

The relevant part of my code is:

```
//SX1278 radio = new Module(LORA_CS, DIO0, LORA_RST, DIO1);
// SX1278 radio = new Module(LORA_CS, DIO0, LORA_RST, DIO1, SPI, SPISettings());  //433Mhz
SX1276 radio = new Module(LORA_CS, DIO0, LORA_RST, DIO1, SPI, SPISettings()); //868Mhz or 915Mhz

// or using RadioShield
// https://github.com/jgromes/RadioShield
//SX1278 radio = RadioShield.ModuleA;

void setup()
{
    Serial.begin(115200);

    // initialize SX1278 with default settings
    Serial.print(F("[SX1278] Initializing ... "));
    SPI.begin(SPI_SCK, SPI_MISO, SPI_MOSI);
    int state = radio.begin(FREQUENCY, BANDWIDTH, SPREADING_FACTOR, CODING_RATE, SX127X_SYNC_WORD, OUTPUT_POWER, PREAMBLE_LEN, GAIN);
    //int state = radio.begin();
    if (state == ERR_NONE)
    {
        Serial.println(F("success!"));
    }
    else
    {
        Serial.print(F("failed, code "));
        Serial.println(state);
        while (true)
            ;
    }
```

I've also tried the first line `SX1278 radio = new Module(LORA_CS, DIO0, LORA_RST, DIO1);` instead of the third line. In each case I get `[SX1278] Initializing ... failed, code -2`

Thanks

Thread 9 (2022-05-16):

How to order & build (PCB fabrication and SMT assembly)

christophecremon, 2022-05-16:
Hello,

Thank you for this wonderful project !
I was wondering : how to order and build the LoRa Soil Moisture Sensor with the help of companies such as JLCPCB, PCBWay or OSH Park ?

Step 1 - Printed circuit board (PCB) fabrication
Step 2 - SMT assembly
1. The bill of materials (BOM) file
2. The pick-and-place file

I am missing : Gerber files, bill of materials (BOM) in English and the pick-and-place file.
I would like ideally to be able to build it in Europe, if this is possible, because I am worried about customs taxes and shipment delays.

Thank you for your help!

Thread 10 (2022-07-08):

Code for Lilygo TTGO Lora32 ESP Module as a receiver

martin3000, 2022-07-08:
/*********
  Rui Santos
  Complete project details at https://RandomNerdTutorials.com/ttgo-lora32-sx1276-arduino-ide/
  needs LoRa library be sandeep mistry

  lora32-receiver
  https://github.com/sandeepmistry/arduino-LoRa/blob/master/API.md
  https://github.com/sandeepmistry/arduino-LoRa
*********/

//Libraries for LoRa
#include <SPI.h>
#include <LoRa.h>

//Libraries for OLED Display
#include <Wire.h>
#include <Adafruit_GFX.h>
#include <Adafruit_SSD1306.h>

//define the pins used by the LoRa transceiver module
#define SCK 5
#define MISO 19
#define MOSI 27
#define SS 18
#define RST 14
#define DIO0 26

//433E6 for Asia
//866E6 for Europe
//915E6 for North America
#define BAND 866E6

//OLED pins
#define OLED_SDA 4
#define OLED_SCL 15
#define OLED_RST 16
#define SCREEN_WIDTH 128 // OLED display width, in pixels
#define SCREEN_HEIGHT 64 // OLED display height, in pixels

Adafruit_SSD1306 display(SCREEN_WIDTH, SCREEN_HEIGHT, &Wire, OLED_RST);

String LoRaData;

void setup() {
  //reset OLED display via software
  pinMode(OLED_RST, OUTPUT);
  digitalWrite(OLED_RST, LOW);
  delay(20);
  digitalWrite(OLED_RST, HIGH);

  //initialize OLED
  Wire.begin(OLED_SDA, OLED_SCL);
  if(!display.begin(SSD1306_SWITCHCAPVCC, 0x3c, false, false)) { // Address 0x3C for 128x32
    Serial.println(F("SSD1306 allocation failed"));
    for(;;); // Don't proceed, loop forever
  }

  display.clearDisplay();
  display.setTextColor(WHITE);
  display.setTextSize(1);
  display.setCursor(0,0);
  display.print("LORA RECEIVER ");
  display.display();

  //initialize Serial Monitor
  Serial.begin(115200);

  //SPI LoRa pins
  SPI.begin(SCK, MISO, MOSI, SS);
  //setup LoRa transceiver module
  LoRa.setPins(SS, RST, DIO0);

  if (!LoRa.begin(BAND)) {
    Serial.println("Starting LoRa failed!");
    while (1);
  }
  LoRa.setSpreadingFactor(9 /*SF9*/);

  //Serial.println("LoRa Initializing OK!");
  display.setCursor(0,10);
  display.println("LoRa Initializing OK!");
  display.display();
}

void loop() {

  //try to parse packet
  int packetSize = LoRa.parsePacket();

  if (packetSize) {
    //received a packet
    Serial.println("Received packet: ");

    LoRaData = "";

    while (LoRa.available()) {
      LoRaData += (char)LoRa.read();
    }

    Serial.println("Message: " + LoRaData);
    Serial.println("RSSI: " + String(LoRa.packetRssi()));
    Serial.println("Snr: " + String(LoRa.packetSnr()));
    Serial.println();

    // Dsiplay information
    display.clearDisplay();
    display.setCursor(0,0);
    display.print("LORA RECEIVER");
    display.setCursor(0,20);
    display.print("Received packet:");
    display.setCursor(0,30);
    display.print(LoRaData);
    display.setCursor(0,40);
    display.print("RSSI:");
    display.setCursor(30,40);
    display.print(LoRa.packetRssi());
    display.display();
  }
}

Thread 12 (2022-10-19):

Slowly increasing moisture reading

gradoj, 2022-10-19:
I see the moisture reading slowly increasing over days especially in mostly dry soil. If I move the probe the reading resets itself so I assume this is polarization. I reduced the time the PWM is on and decreased the number of readings but still see the effect to a lesser extent at the default 2MHz. Any ideas how to further reduce this or depolarize it somehow? This graph attached shows moisture slowly increasing and then where I wiggle the probe around a little and moisture content drops
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

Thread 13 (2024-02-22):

ESP32-Receiver.ino doesn't compile

fredmccr, 2024-02-22:
Hi,

The code given on V3/example/ESP32-Receiver/ESP32-Receiver.ino doesn't compile in Arduino IDE, giving an error (on the web page heading construction part) at line:
**client.println(str);
'str was not declared in this scope'**

I'm using a "MaESP ESP32 Lora Gateway" as a receiver.
If I comment the faulty line, I can upload the code, everything works well on the OLED screen, but of course the string (ID, temp, ...) is not displayed on the published web page.

Can someone please help me in fixing that ?
Thanks in advance!

fredmccr, 2024-02-25:
I found out what was wrong: "String str;" was not at the right position in the sketch. OK after I moved it (and moved "String sensorADC;" as well) just before "void setup()"

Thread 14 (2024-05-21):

Change Frequency of Moisture Sensor

cHeeSaW, 2024-05-21:
Hi,

i mistakenly ordered the 915Mhz version, is it possible to change the frequency to 868Mhz with just changing the variable in the code or is the built in hardware just supporting the frequency i bought? I would appreciate if anybody can give me some information. Thanks!

cHeeSaW, 2024-05-31:
The answer is: Yes, it works!

Closed 2024-05-31.

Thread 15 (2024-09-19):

Sketch too large

lhvu85, 2024-09-19:
I'm having issues compiling Moisture_LowPower_RadioLib_v2.1.ino.  After correcting SX127X and setting ERR_NONE to 0, it says "Sketch uses 33434 bytes (108%) of program storage space. Maximum is 30720 bytes." (sketch is too big).  I tried removing all the comments like someone else mentioned, but it wasn't enough.

Also which board are we suppose to use?  Is it Arduino Pro or Pro Mini and choose ATmega328p 3.3V?   Does someone have a working .ino file you can share? Thanks!

ljteam, 2024-10-02:
Same issue here, very frustrating :(

ljteam, 2024-10-02:
Replying to myself if this can help you @lhvu85 : I managed to compile the sketch by selecting an older verson of the Radiolib library (I guess it was smaller before)

cHeeSaW, 2024-11-04:
can anyone of you tell me which version you used? :)

ljteam, 2024-11-04:
Yep, I used Radiolib v6.4.2
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

cHeeSaW, 2024-11-08:
Thank you!

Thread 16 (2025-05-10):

still no schematic for V3

urs8000, 2025-05-10:
in the V3-folder is an old (V1.2) version with the 555 chip
please update it with the correct version 3

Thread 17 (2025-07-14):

SenseLoRA reciever

karlfife, 2025-07-14:
It's not clear based on anything I can find whether the SenseLoRa reciever can be used as a generic receiver for this Sensor V3

i.e.
https://www.makerfabs.com/senselora-lora-receiver.html
and
https://www.makerfabs.com/lora-soil-moisture-sensor-v3.html

One might assume that it would be by simply pluging into USB on a Linux system e.g. /dev/serial/... etc.  and start streaming out the data
e.g.
ID010003 REPLY : SOIL INEDX:0 H:48.85 T:30.50 ADC:896 BAT:1016

I's not clear whether the SenseLora receiver would be compatible since it explicitly states:
"This Lora receiver is designed to work with Makefabs SenseLora modules",
And the v3 sensor is not listed.  Maybe there's something special about the SenseLoRa device firmware that would make it not 'just work'?

Please advise.

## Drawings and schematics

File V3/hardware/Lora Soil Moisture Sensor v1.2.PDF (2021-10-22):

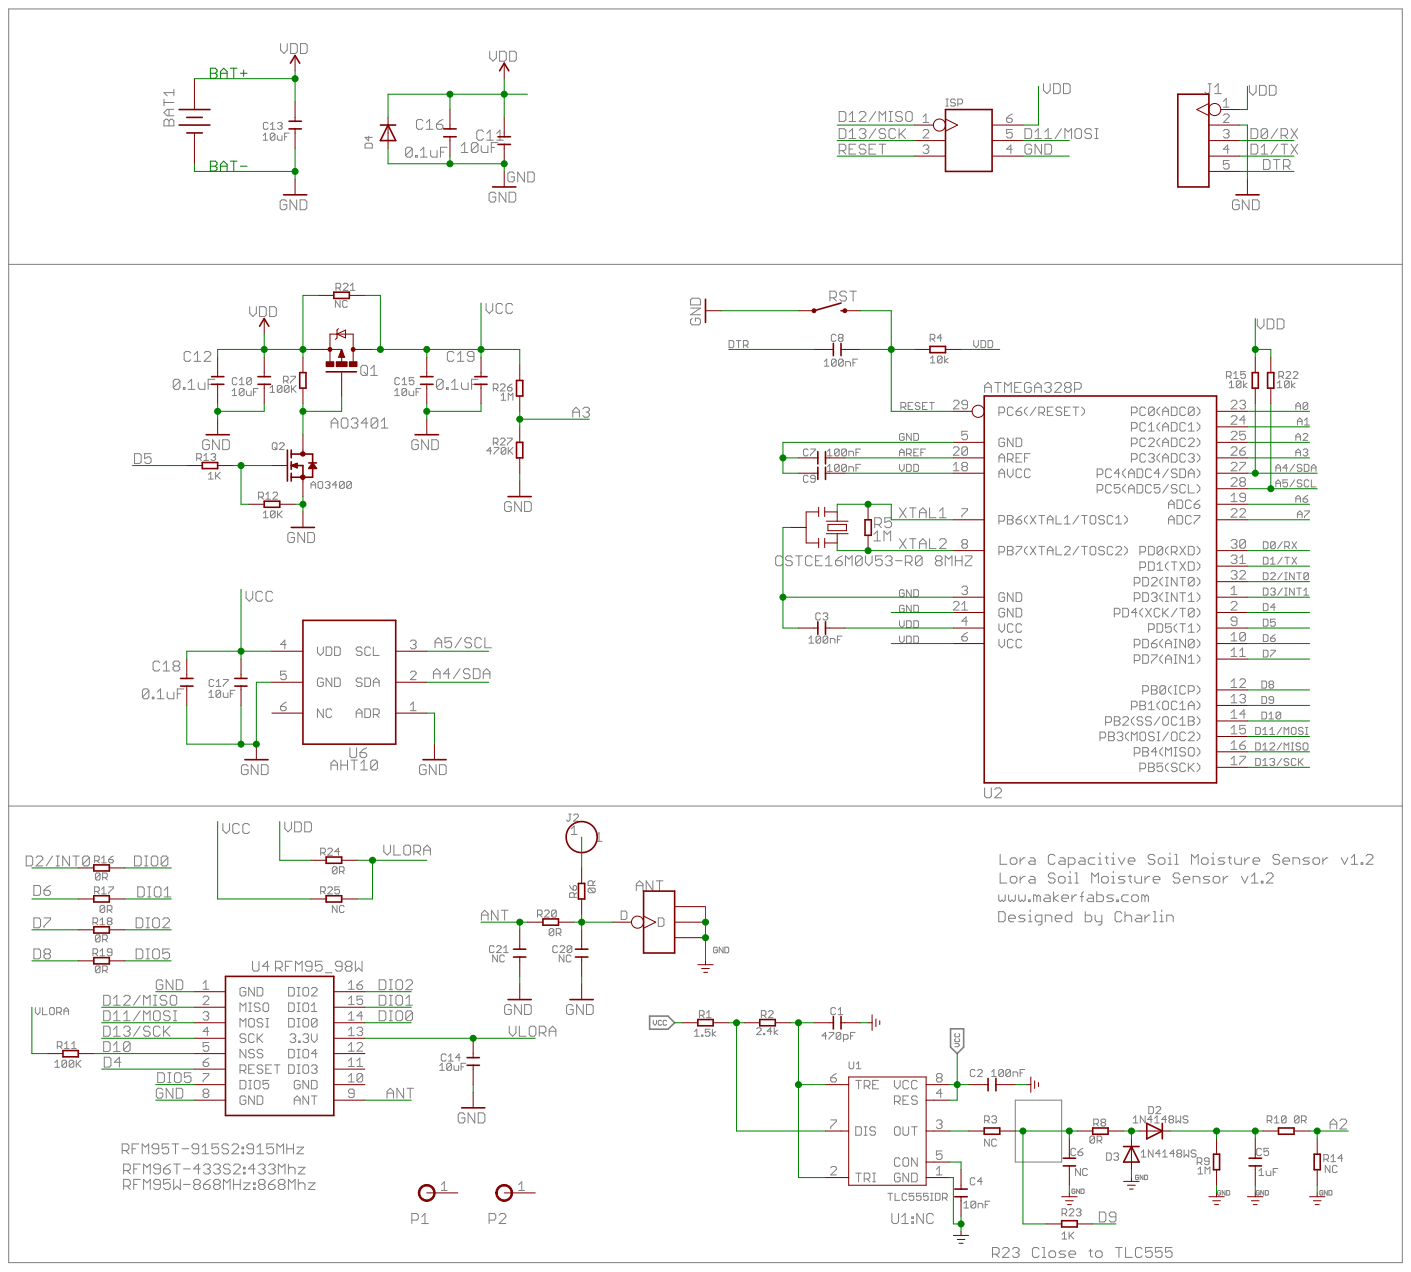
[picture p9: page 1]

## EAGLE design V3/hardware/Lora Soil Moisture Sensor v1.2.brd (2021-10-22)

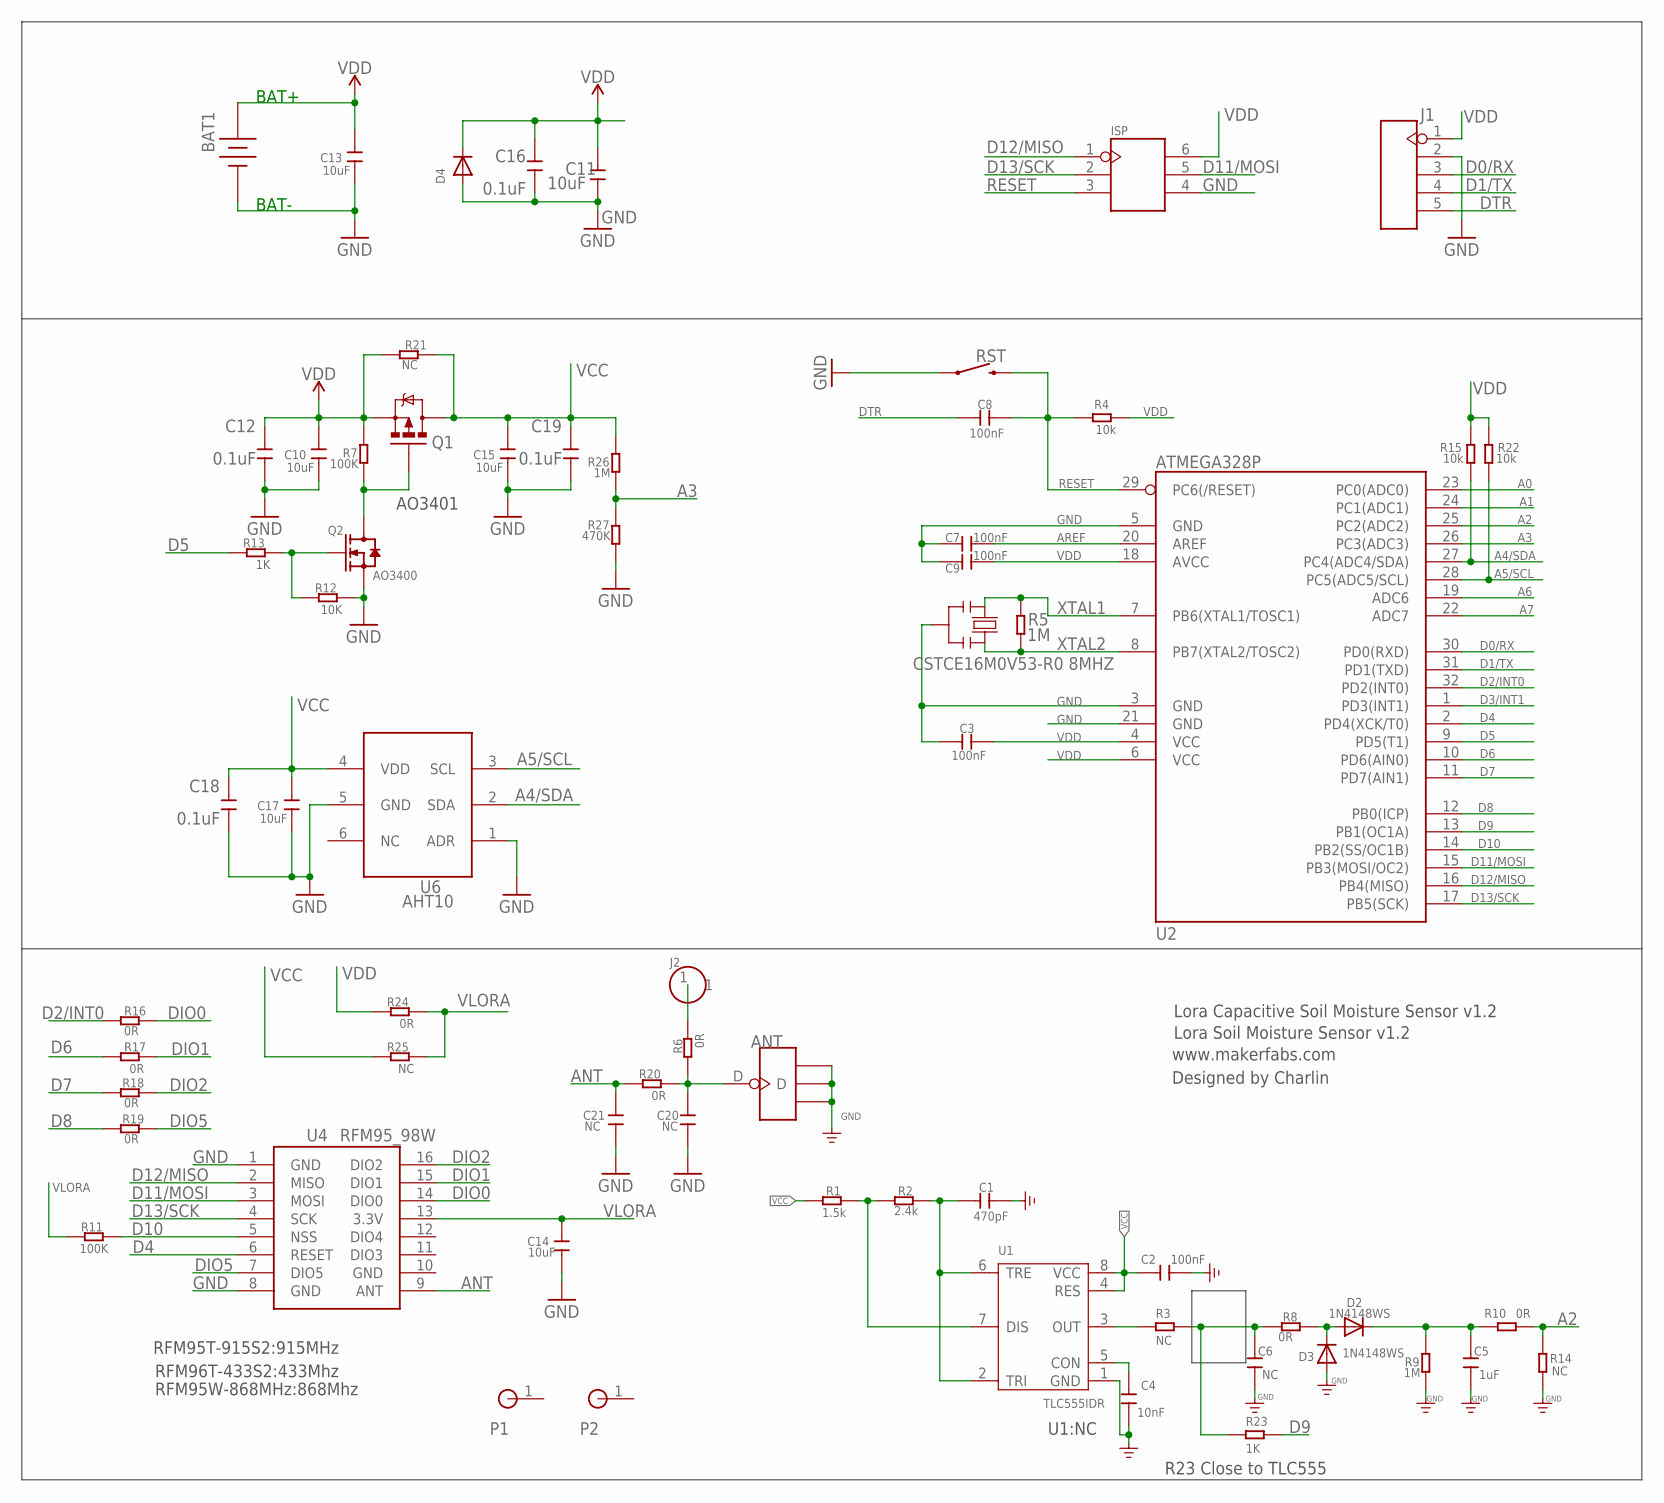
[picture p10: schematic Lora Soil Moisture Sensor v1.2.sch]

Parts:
ANT: ANTENNA-U-FL; 4P-U-FL
BAT1: 18650
C1: 470pF; C0603
C2: 100nF; C0603
C3, C7, C8, C9: 100nF; 0603
C4: 10nF; C0603
C5: 1uF; DISCRETE_C0603
C6: NC; DISCRETE_C0603
C10, C11, C13, C14, C15, C17: 10uF; 0603
C12, C16, C18, C19: 0.1uF; 0603
C20, C21: NC; 0603
D2, D3: 1N4148WS; SOD-323F
D4: DIODESOD-323F; SOD-323F
ISP: HEADER-2X3P-SMD; 2X3P-2.54-SMD
J1: HEADER-5P-2.54; 5P-2.54
J2: HEADER-1P-50; 1P-100/50MIL
P1, P2: HOLE-P1-2.2; MTGNP1-220-1MM
Q1: MOSFET-PCHANNEL; SOT23-3
Q2: AO3400; DISCRETE_SOT23
R1: 1.5k; R0603
R2: 2.4k; R0603
R3, R14, R21, R25: NC; R0603
R4, R15, R22: 10k; R0603
R5, R9, R26: 1M; R0603
R6, R8, R10, R16, R17, R18, R19, R20, R24: 0R; R0603
R7, R11: 100K; R0603
R12: 10K; R0603
R13, R23: 1K; R0603
R27: 470K; R0603
RST: MOMENTARY-SWITCH-SPST-SMD-6.0X3.5MM; TACTILE_SWITCH_SMD_6.0X3.5MM
U1: TLC555IDR; SOIC8-1.27-5X4MM
U2: ATMEGA328P; TQFP32
U4: RFM95_98W; RFM92_93W
U6: AHT10; SMD6-127P-400L500W
Y1: CSTCE16M0V53-R0 8MHZ; RESONATOR

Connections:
A0: U2.23 (PC0(ADC0))
A1: U2.24 (PC1(ADC1))
A2: R10.2, R14.1, U2.25 (PC2(ADC2))
A3: R26.1, R27.2, U2.26 (PC3(ADC3))
A4/SDA: R15.2, U2.27 (PC4(ADC4/SDA)), U6.2 (SDA)
A5/SCL: R22.2, U2.28 (PC5(ADC5/SCL)), U6.3 (SCL)
A6: U2.19 (ADC6)
A7: U2.22 (ADC7)
ANT: C21.2, R20.2, U4.9 (ANT)
AREF: C7.2, U2.20 (AREF)
D0/RX: J1.3, U2.30 (PD0(RXD))
D1/TX: J1.4, U2.31 (PD1(TXD))
D2/INT0: R16.1, U2.32 (PD2(INT0))
D3/INT1: U2.1 (PD3(INT1))
D4: U2.2 (PD4(XCK/T0)), U4.6 (RESET)
D5: R13.2, U2.9 (PD5(T1))
D6: R17.1, U2.10 (PD6(AIN0))
D7: R18.1, U2.11 (PD7(AIN1))
D8: R19.1, U2.12 (PB0(ICP))
D9: R23.2, U2.13 (PB1(OC1A))
D10: R11.1, U2.14 (PB2(SS/OC1B)), U4.5 (NSS)
D11/MOSI: ISP.5, U2.15 (PB3(MOSI/OC2)), U4.3 (MOSI)
D12/MISO: ISP.1, U2.16 (PB4(MISO)), U4.2 (MISO)
D13/SCK: ISP.2, U2.17 (PB5(SCK)), U4.4 (SCK)
DIO0: R16.2, U4.14 (DIO0)
DIO1: R17.2, U4.15 (DIO1)
DIO2: R18.2, U4.16 (DIO2)
DIO5: R19.2, U4.7 (DIO5)
DTR: C8.1, J1.5
GND: ANT.GND1, ANT.GND2, ANT.GND3, BAT1.2, C1.1, C2.1, C3.1, C4.2, C5.1, C6.1, C7.1, C9.1, C10.1, C11.1, C12.1, C13.1, C14.1, C15.1, C16.1, C17.1, C18.1, C19.1, C20.1, C21.1, D3.A, D4.A, ISP.4, J1.2, Q2.2 (S), R9.1, R12.1, R14.2, R27.1, RST.1, U1.1 (GND), U2.3 (GND), U2.5 (GND), U2.21 (GND), U4.1 (GND), U4.8 (GND), U4.10 (GND), U6.1 (ADR), U6.5 (GND), Y1.2
unnamed: R1.1, R2.2, U1.7 (DIS)
unnamed: C1.2, R2.1, U1.2 (TRI), U1.6 (TRE)
unnamed: C4.1, U1.5 (CON)
unnamed: R3.1, U1.3 (OUT)
unnamed: C6.2, R3.2, R8.1, R23.1
unnamed: J2.1, R6.1
unnamed: Q1.1 (G), Q2.3 (D), R7.1
unnamed: D2.A, D3.C, R8.2
unnamed: Q2.1 (G), R12.2, R13.1
unnamed: C5.2, D2.C, R9.2, R10.1
unnamed: ANT.D, C20.2, R6.2, R20.1
RESET: C8.2, ISP.3, R4.2, RST.2, U2.29 (PC6(/RESET))
VCC: C2.2, C15.2, C17.2, C18.2, C19.2, Q1.3 (D), R1.2, R21.1, R25.2, R26.2, U1.4 (RES), U1.8 (VCC), U6.4 (VDD)
VDD: BAT1.1, C3.2, C9.2, C10.2, C11.2, C12.2, C13.2, C16.2, D4.C, ISP.6, J1.1, Q1.2 (S), R4.1, R7.2, R15.1, R21.2, R22.1, R24.2, U2.4 (VCC), U2.6 (VCC), U2.18 (AVCC)
VLORA: C14.2, R11.2, R24.1, R25.1, U4.13 (3.3V)
XTAL1: R5.2, U2.7 (PB6(XTAL1/TOSC1)), Y1.1
XTAL2: R5.1, U2.8 (PB7(XTAL2/TOSC2)), Y1.3

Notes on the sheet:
RFM95T-915S2:915MHz
RFM96T-433S2:433Mhz
RFM95W-868MHz:868Mhz
Lora Soil Moisture Sensor v1.2
R23 Close to TLC555
www.makerfabs.com
Lora Capacitive Soil Moisture Sensor v1.2
Designed by Charlin
BAT+
BAT-
AO3401
U1:NC

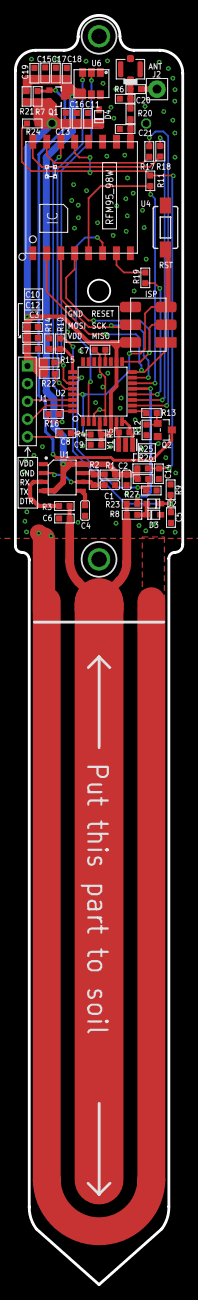
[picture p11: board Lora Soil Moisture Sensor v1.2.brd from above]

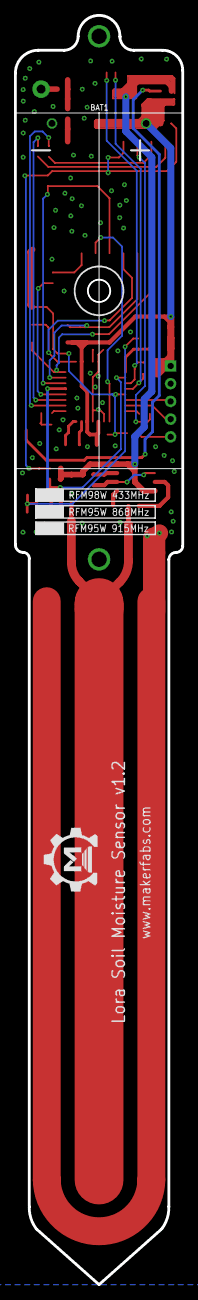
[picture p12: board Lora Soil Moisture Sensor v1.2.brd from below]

Board: 2 copper layers, 24.0 x 182.0 mm, 67 parts (2 on the bottom side), 42 nets.

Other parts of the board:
U$7: MAKERFABS_0.3

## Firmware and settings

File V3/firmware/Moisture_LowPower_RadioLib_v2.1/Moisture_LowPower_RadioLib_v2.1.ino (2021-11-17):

#include <SPI.h>
#include <Wire.h>
#include <RadioLib.h>
#include <avr/wdt.h>
#include <avr/sleep.h>
#include "I2C_AHT10.h"

//#define NODENAME "LORA_POWER_1"
String node_id = String("ID") + "010000";

//Set sleep time, when value is 1 almost sleep 20s,when value is 450, almost 1 hour.
#define SLEEP_CYCLE 450

//Lora set
//Set Lora frequency
// #define FREQUENCY 434.0
// #define FREQUENCY 868.0
#define FREQUENCY 915.0

#define BANDWIDTH 125.0
#define SPREADING_FACTOR 9
#define CODING_RATE 7
#define OUTPUT_POWER 10
#define PREAMBLE_LEN 8
#define GAIN 0

//328p
#define DIO0 2
#define DIO1 6

#define LORA_RST 4
#define LORA_CS 10

#define SPI_MOSI 11
#define SPI_MISO 12
#define SPI_SCK 13

//pin set
#define VOLTAGE_PIN A3
#define PWM_OUT_PIN 9
#define SENSOR_POWER_PIN 5
#define ADC_PIN A2

#define DEBUG_OUT_ENABLE 1

SX1276 radio = new Module(LORA_CS, DIO0, LORA_RST, DIO1);
AHT10 humiditySensor;

bool readSensorStatus = false;
int sensorValue = 0; // variable to store the value coming from the sensor
int batValue = 0;    // the voltage of battery
int count = 0;
int ADC_O_1;           // ADC Output First 8 bits
int ADC_O_2;           // ADC Output Next 2 bits
int16_t packetnum = 0; // packet counter, we increment per xmission
float temperature = 0.0;
float humidity = 0.0;

bool AHT_init()
{
    bool ret = false;
    Wire.begin();
    if (humiditySensor.begin() == false)
    {
#if DEBUG_OUT_ENABLE
        Serial.println("AHT10 not detected. Please check wiring. Freezing.");
#endif
    }

    if (humiditySensor.available() == true)
    {
        temperature = humiditySensor.getTemperature();
        humidity = humiditySensor.getHumidity();
        ret = true;
    }
    if (isnan(humidity) || isnan(temperature))
    {
#if DEBUG_OUT_ENABLE
        Serial.println(F("Failed to read from AHT sensor!"));
#endif
    }
    return ret;
}
void Lora_init()
{
    int state = radio.begin(FREQUENCY, BANDWIDTH, SPREADING_FACTOR, CODING_RATE, SX127X_SYNC_WORD, OUTPUT_POWER, PREAMBLE_LEN, GAIN);
    if (state == ERR_NONE)
    {
#if DEBUG_OUT_ENABLE
        Serial.println(F("success!"));
#endif
    }
    else
    {
#if DEBUG_OUT_ENABLE
        Serial.print(F("failed, code "));
        Serial.println(state);
#endif
        // while (true)
        //     ;
    }
}
void setup()
{
#if DEBUG_OUT_ENABLE
    Serial.begin(115200);
    Serial.println("Soil start.");
#endif
    delay(100);

    // set up Timer 1
    pinMode(PWM_OUT_PIN, OUTPUT);

    TCCR1A = bit(COM1A0);            // toggle OC1A on Compare Match
    TCCR1B = bit(WGM12) | bit(CS10); // CTC, scale to clock
    OCR1A = 1;

    pinMode(LORA_RST, OUTPUT);
    digitalWrite(LORA_RST, HIGH);
    delay(100);

    pinMode(SENSOR_POWER_PIN, OUTPUT);
    digitalWrite(SENSOR_POWER_PIN, HIGH); //Sensor power on
    delay(100);

    Lora_init();

    Wire.begin();
    if (humiditySensor.begin() == false)
    {

#if DEBUG_OUT_ENABLE
        Serial.println("AHT10 not detected. Please check wiring. Freezing.");
#endif
    }
#if DEBUG_OUT_ENABLE
    else
        Serial.println("AHT10 acknowledged.");
#endif

    do_some_work();
//setup over
#if DEBUG_OUT_ENABLE
    Serial.println("[Set]Sleep Mode Set");
#endif
    low_power_set();
}

void loop()
{
    wdt_disable();

    if (count > SLEEP_CYCLE) //(7+1) x 8S  450
    {
#if DEBUG_OUT_ENABLE
        //code start
        Serial.println("Code start>>");
#endif

        do_some_work();
        all_pins_low();

#if DEBUG_OUT_ENABLE
        //code end
        Serial.println("Code end<<");
#endif
        //count init
        count = 0;
    }

    low_power_set();
}

ISR(WDT_vect)
{
#if DEBUG_OUT_ENABLE
    Serial.print("[Watch dog]");
    Serial.println(count);
#endif
    delay(100);
    count++;
    //wdt_reset();
    wdt_disable(); // disable watchdog
}

//Set low power mode and into sleep
void low_power_set()
{
    all_pins_low();
    delay(10);
    // disable ADC
    ADCSRA = 0;

    sleep_enable();
    watchdog_init();
    set_sleep_mode(SLEEP_MODE_PWR_DOWN);
    delay(10);
    noInterrupts();
    sleep_enable();

    // turn off brown-out enable in software
    MCUCR = bit(BODS) | bit(BODSE);
    MCUCR = bit(BODS);
    interrupts();

    sleep_cpu();
    sleep_disable();
}

//Enable watch dog
void watchdog_init()
{
    // clear various "reset" flags
    MCUSR = 0;
    // allow changes, disable reset
    WDTCSR = bit(WDCE) | bit(WDE);
    WDTCSR = bit(WDIE) | bit(WDP3) | bit(WDP0); // set WDIE, and 8 seconds delay
    wdt_reset();                                // pat the dog
}

void do_some_work()
{

    digitalWrite(SENSOR_POWER_PIN, HIGH); // Sensor/RF95 power on
    digitalWrite(LORA_RST, HIGH);
    delay(5);
    pinMode(PWM_OUT_PIN, OUTPUT);    //digitalWrite(PWM_OUT_PIN, LOW);
    TCCR1A = bit(COM1A0);            // toggle OC1A on Compare Match
    TCCR1B = bit(WGM12) | bit(CS10); // CTC, scale to clock
    OCR1A = 1;                       // compare A register value (5000 * clock speed / 1024).When OCR1A == 1, PWM is 2MHz

    Lora_init();
    delay(50);

    //ADC2  AVCC as reference voltage
    ADMUX = _BV(REFS0) | _BV(MUX1);

    //ADC2  internal 1.1V as ADC reference voltage
    //ADMUX = _BV(REFS1) |_BV(REFS0) | _BV(MUX1);

    // 8  分频
    ADCSRA = _BV(ADEN) | _BV(ADPS1) | _BV(ADPS0);
    delay(50);
    for (int i = 0; i < 3; i++)
    {
        //start ADC conversion
        ADCSRA |= (1 << ADSC);

        delay(10);

        if ((ADCSRA & 0x40) == 0)
        {
            ADC_O_1 = ADCL;
            ADC_O_2 = ADCH;

            sensorValue = (ADC_O_2 << 8) + ADC_O_1;
            ADCSRA |= 0x40;
#if DEBUG_OUT_ENABLE
            Serial.print("ADC:");
            Serial.println(sensorValue);
#endif

            if (readSensorStatus == false)
                readSensorStatus = AHT_init();
        }
        ADCSRA |= (1 << ADIF); //reset as required
        delay(50);
    }

    //ADC3  internal 1.1V as ADC reference voltage
    ADMUX = _BV(REFS1) | _BV(REFS0) | _BV(MUX1) | _BV(MUX0);

    delay(50);
    for (int i = 0; i < 3; i++)
    {
        //start ADC conversion
        ADCSRA |= (1 << ADSC);

        delay(10);
        
        if ((ADCSRA & 0x40) == 0)
        {
            ADC_O_1 = ADCL;
            ADC_O_2 = ADCH;

            batValue = (ADC_O_2 << 8) + ADC_O_1;
            ADCSRA |= 0x40;
#if DEBUG_OUT_ENABLE
            Serial.print("BAT:");
            Serial.println(batValue);
            float bat = (float)batValue * 3.3;
            bat = bat / 1024.0;
            Serial.print(bat);
            Serial.print("V");
#endif
        }
        ADCSRA |= (1 << ADIF); //reset as required
        delay(50);
    }
    send_lora();
    delay(1000);
    radio.sleep();

    packetnum++;
    readSensorStatus = false;
    digitalWrite(SENSOR_POWER_PIN, LOW); // Sensor/RF95 power off
    delay(100);
}

void all_pins_low()
{
    pinMode(PWM_OUT_PIN, INPUT);
    pinMode(A4, INPUT_PULLUP);
    pinMode(A5, INPUT_PULLUP);

    delay(50);
}

void send_lora()
{
    String message = "INEDX:" + (String)packetnum + " H:" + (String)humidity + " T:" + (String)temperature + " ADC:" + (String)sensorValue + " BAT:" + (String)batValue;
    String back_str = node_id + " REPLY : SOIL " + message;

#if DEBUG_OUT_ENABLE
    Serial.println(back_str);
#endif

    radio.transmit(back_str);
}

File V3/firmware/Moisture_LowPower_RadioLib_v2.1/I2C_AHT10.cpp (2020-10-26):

/****************************************************************

 ***************************************************************/

#include "I2C_AHT10.h"

/*--------------------------- Device Status ------------------------------*/
bool AHT10::begin(TwoWire &wirePort)
{
    _i2cPort = &wirePort; //Grab the port the user wants to communicate on

    _deviceAddress = AHT10_DEFAULT_ADDRESS; //We had hoped the AHT10 would support two addresses but it doesn't seem to

    if (isConnected() == false)
        return false;

    //Wait 40 ms after power-on before reading temp or humidity. Datasheet pg 8
    delay(40);

    //Check if the calibrated bit is set. If not, init the sensor.
    if (isCalibrated() == false)
    {
        //Send 0xBE0800
        initialize();

        //Immediately trigger a measurement. Send 0xAC3300
        triggerMeasurement();

        delay(75); //Wait for measurement to complete

        uint8_t counter = 0;
        while (isBusy())
        {
            delay(1);
            if (counter++ > 100)
                return (false); //Give up after 100ms
        }

        //This calibration sequence is not completely proven. It's not clear how and when the cal bit clears
        //This seems to work but it's not easily testable
        if (isCalibrated() == false)
        {
            return (false);
        }
    }

    //Check that the cal bit has been set
    if (isCalibrated() == false)
        return false;

    //Mark all datums as fresh (not read before)
    sensorQueried.temperature = true;
    sensorQueried.humidity = true;

    return true;
}

//Ping the AHT10's I2C address
//If we get a response, we are correctly communicating with the AHT10
bool AHT10::isConnected()
{
    _i2cPort->beginTransmission(_deviceAddress);
    if (_i2cPort->endTransmission() == 0)
        return true;

    //If IC failed to respond, give it 20ms more for Power On Startup
    //Datasheet pg 7
    delay(20);

    _i2cPort->beginTransmission(_deviceAddress);
    if (_i2cPort->endTransmission() == 0)
        return true;

    return false;
}

/*------------------------ Measurement Helpers ---------------------------*/

uint8_t AHT10::getStatus()
{
    _i2cPort->requestFrom(_deviceAddress, (uint8_t)1);
    if (_i2cPort->available())
        return (_i2cPort->read());
    return (0);
}

//Returns the state of the cal bit in the status byte
bool AHT10::isCalibrated()
{
    return (getStatus() & (1 << 3));
}

//Returns the state of the busy bit in the status byte
bool AHT10::isBusy()
{
    return (getStatus() & (1 << 7));
}

bool AHT10::initialize()
{
    _i2cPort->beginTransmission(_deviceAddress);
    _i2cPort->write(sfe_aht10_reg_initialize);
    _i2cPort->write(0x80);
    _i2cPort->write(0x00);
    if (_i2cPort->endTransmission() == 0)
        return true;
    return false;
}

bool AHT10::triggerMeasurement()
{
    _i2cPort->beginTransmission(_deviceAddress);
    _i2cPort->write(sfe_aht10_reg_measure);
    _i2cPort->write(0x33);
    _i2cPort->write(0x00);
    if (_i2cPort->endTransmission() == 0)
        return true;
    return false;
}

//Loads the
void AHT10::readData()
{
    //Clear previous data
    sensorData.temperature = 0;
    sensorData.humidity = 0;

    if (_i2cPort->requestFrom(_deviceAddress, (uint8_t)6) > 0)
    {
        uint8_t state = _i2cPort->read();

        uint32_t incoming = 0;
        incoming |= (uint32_t)_i2cPort->read() << (8 * 2);
        incoming |= (uint32_t)_i2cPort->read() << (8 * 1);
        uint8_t midByte = _i2cPort->read();

        incoming |= midByte;
        sensorData.humidity = incoming >> 4;

        sensorData.temperature = (uint32_t)midByte << (8 * 2);
        sensorData.temperature |= (uint32_t)_i2cPort->read() << (8 * 1);
        sensorData.temperature |= (uint32_t)_i2cPort->read() << (8 * 0);

        //Need to get rid of data in bits > 20
        sensorData.temperature = sensorData.temperature & ~(0xFFF00000);

        //Mark data as fresh
        sensorQueried.temperature = false;
        sensorQueried.humidity = false;
    }
}

//Triggers a measurement if one has not been previously started, then returns false
//If measurement has been started, checks to see if complete.
//If not complete, returns false
//If complete, readData(), mark measurement as not started, return true
bool AHT10::available()
{
    if (measurementStarted == false)
    {
        triggerMeasurement();
        measurementStarted = true;
        return (false);
    }

    if (isBusy() == true)
    {
        return (false);
    }

    readData();
    measurementStarted = false;
    return (true);
}

bool AHT10::softReset()
{
    _i2cPort->beginTransmission(_deviceAddress);
    _i2cPort->write(sfe_aht10_reg_reset);
    if (_i2cPort->endTransmission() == 0)
        return true;
    return false;
}

/*------------------------- Make Measurements ----------------------------*/

float AHT10::getTemperature()
{
    if (sensorQueried.temperature == true)
    {
        //We've got old data so trigger new measurement
        triggerMeasurement();

        delay(75); //Wait for measurement to complete

        uint8_t counter = 0;
        while (isBusy())
        {
            delay(1);
            if (counter++ > 100)
                return (false); //Give up after 100ms
        }

        readData();
    }

    //From datasheet pg 8
    float tempCelsius = ((float)sensorData.temperature / 1048576) * 200 - 50;

    //Mark data as old
    sensorQueried.temperature = true;

    return tempCelsius;
}

float AHT10::getHumidity()
{
    if (sensorQueried.humidity == true)
    {
        //We've got old data so trigger new measurement
        triggerMeasurement();

        delay(75); //Wait for measurement to complete

        uint8_t counter = 0;
        while (isBusy())
        {
            delay(1);
            if (counter++ > 100)
                return (false); //Give up after 100ms
        }

        readData();
    }

    //From datasheet pg 8
    float relHumidity = ((float)sensorData.humidity / 1048576) * 100;

    //Mark data as old
    sensorQueried.humidity = true;

    return relHumidity;
}

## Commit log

2020-08-24 add pcb
    [Lora Soil Moisture Sensor v1.1.brd, Lora Soil Moisture Sensor v1.1.sch]
2020-10-26 v2.2 power save
2021-09-17 Repair battery read adc bug.
    [I2C_AHT10.cpp, Moisture_LowPower_RadioLib_v2.1.ino]
2021-10-22 Reorganize the file structure
    [Lora Soil Moisture Sensor BOM V1.1.xlsx, Lora Soil Moisture Sensor BOM V1.3.xlsx, Lora Soil Moisture Sensor v1.1.brd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]
2021-10-22 create MakePython ESP32 receiver
2021-11-17 Change Pin Define

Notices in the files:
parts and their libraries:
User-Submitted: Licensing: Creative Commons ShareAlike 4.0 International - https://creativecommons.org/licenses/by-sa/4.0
